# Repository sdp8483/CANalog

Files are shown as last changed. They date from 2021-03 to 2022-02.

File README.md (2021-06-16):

# CANalog

CAN to analog converter.

## TODO
### PCB
- [x] Add resistor to stm32 reset line so that stm32 programmer can reset uC when esp8266 is pulling pin high
- [x] Increase clearance between terminals and mounting holes by about 1mm
- [x] Increase spacing between aout terminal and CAN terminal, possibly center CAN terminal.
### WiFi Interface Firmware
- [ ] fix webpage layout for mobile devices
- [ ] aout control for analog calibration
- [ ] setup over the air update for esp8266 firmware
### CAN Interface Firmware
- [ ] LED persistance for CAN activity
- [ ] setup bootloader over spi for wifi update of firmware
- [ ] setup CAN filtering
- [ ] test std ID CAN messages
- [ ] test timing

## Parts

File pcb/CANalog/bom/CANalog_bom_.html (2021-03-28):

Source File | CANalog.sch
BoM Date | Sun 28 Mar 2021 03:16:26 PM EDT
Schematic Version
Schematic Date
PCB Variant | default
KiCad Version | Eeschema 5.1.9
Component Groups | 49
Component Count (per PCB) | 83
Fitted Components (per PCB) | 83
Number of PCBs | 1
Total Component Count (for 1 PCBs) | 83
 | Description | Part | References | Value | Footprint | Quantity Per PCB | Datasheet | Population
1 | Unpolarized capacitor | C | C9 | 33pF | C_0603_1608Metric | 1 | ~
2 | Unpolarized capacitor | C | C3 C5 C6 C8 C10 C11 | 100nF |  | 6 | ~
3 | Unpolarized capacitor | C | C4 C12 C16 C18 C19 | 0.1uF | C_0805_2012Metric | 5 | ~
4 | Unpolarized capacitor | C | C2 C13 C15 | 1uF |  | 3 | ~
5 | Unpolarized capacitor | C | C17 | 1uF | C_0805_2012Metric | 1 | ~
6 | Unpolarized capacitor | C | C1 | 4.7uF | C_0805_2012Metric | 1 | ~
7 | Unpolarized capacitor | C | C7 C14 | 10uF | C_0805_2012Metric | 2 | ~
8 | Diode | D | D9 | 1N4148 | D_DO-35_SOD27_P7.62mm_Horizontal | 1 | ~
9 | Zener diode | D_Zener | D1 | BZV55-C15 | Nexperia_BZV55_SOD80C | 1 | ~
10 | Diode | D | D5 | D |  | 1 | ~
11 | Light emitting diode | LED | D3 D6 D7 D8 | LED | LED_0603_1608Metric | 4 | ~
12 |  | PESD1CAN-UX | D10 | PESD1CAN-UX | SOT-323_SC-70 | 1
13 | Schottky diode | D_Schottky | D2 D4 | SS14F | SMAF | 2 | ~
14 | Ferrite bead, small symbol | Ferrite_Bead_Small | FB1 FB2 | FBS |  | 2 | ~
15 | Generic connector, single row, 01x03, script generated (kicad-library-utils/schlib/autogen/connector/) | Conn_01x03 | J8 | CAN |  | 1 | ~
16 | Generic connector, single row, 01x06, script generated (kicad-library-utils/schlib/autogen/connector/) | Conn_01x06 | J6 | ESP_PROG | PinHeader_1x06_P2.54mm_Vertical | 1 | ~
17 | Generic connector, single row, 01x04, script generated (kicad-library-utils/schlib/autogen/connector/) | Conn_01x04 | J4 J5 | I2C2 |  | 2 | ~ | DNP
18 | Generic connector, single row, 01x02, script generated (kicad-library-utils/schlib/autogen/connector/) | Conn_01x02 | J1 J7 | PWR | WJ127-5.0-2P | 2 | ~
19 | Generic connector, single row, 01x06, script generated (kicad-library-utils/schlib/autogen/connector/) | Conn_01x06 | J3 | SPI3 |  | 1 | ~ | DNP
20 | USB Micro Type B connector | USB_B_Micro | J2 | USB_B_Micro | USB_Micro-B_Amphenol_10103594-0001LF_Horizontal | 1 | ~
21 | Jumper, normally open, small symbol | Jumper_NO_Small | JP3 | BOOT0 | PinHeader_1x02_P2.54mm_Vertical | 1 | ~
22 | Jumper, normally closed, small symbol | Jumper_NC_Small | JP1 JP2 | NC |  | 2 | ~
23 | Inductor | L | L1 | 2.2uH | L_3.5mmx3.0mm_SMD | 1 | ~
24 | P-MOSFET transistor, gate/source/drain | Q_PMOS_GSD | Q1 Q3 | DMP3099L-7 | SOT-23 | 2 | ~
25 | NPN transistor, base/emitter/collector | Q_NPN_BEC | Q2 | MMBT2222A | SOT-23 | 1 | ~
26 | Resistor | R | R1 R2 | 0 | R_0805_2012Metric | 2 | ~
27 | Resistor | R | R26 | 120 | R_0805_2012Metric | 1 | ~
28 | Resistor | R | R8 R11 R22 R23 R24 | 1k | R_0805_2012Metric | 5 | ~
29 | Resistor | R | R7 | 1.5k | R_0805_2012Metric | 1 | ~
30 | Resistor | R | R3 R4 R12 R15 R16 R17 | 10k | R_0805_2012Metric | 6 | ~
31 | Resistor | R | R18 | 10k |  | 1 | ~
32 | Resistor | R | R20 | 12k | R_0805_2012Metric | 1 | ~
33 | Resistor | R | R5 R6 | 20k | R_0805_2012Metric | 2 | ~
34 | Resistor | R | R10 | 21k | R_0805_2012Metric | 1 | ~
35 | Resistor | R | R21 | 68k | R_0805_2012Metric | 1 | ~
36 | Resistor | R | R19 | 120k | R_0805_2012Metric | 1 | ~
37 | Resistor | R | R9 | 124k | R_0805_2012Metric | 1 | ~
38 | Resistor | R | R13 R14 | R |  | 2 | ~ | DNP
39 | Resistor | R | R25 | R | R_0805_2012Metric | 1 | ~
40 | Push button switch, generic, two pins | SW_Push | SW1 SW2 | SW_Push | SW_PUSH_6mm | 2 | ~
41 |  | 74AHC1G66 | U7 | 74AHC1G66 | SOT-353_SC-70-5 | 1
42 | DCD Step Down Converter | BL9342 | U1 | BL9342 | SOT-23-6 | 1 | https://datasheet.lcsc.com/szlcsc/1809050135_BL-Shanghai-Belling-BL9342_C93176.pdf
43 | ESP8266 ESP-12E module, 22 pins, 2mm, PCB antenna | ESP-12E | U5 | ESP-12E | ESP-12E_SMD | 1 | http://l0l.org.uk/2014/12/esp8266-modules-hardware-guide-gotta-catch-em-all/
44 | Low-Voltage Rail-to-Rail Output Operational Amplifiers, SOT-23-5/SC-70-5 | LMV321 | U2 | LMV321 |  | 1 | http://www.ti.com/lit/ds/symlink/lmv324.pdf
45 | 300mA Low-dropout Voltage Regulator, Vout 3.3V, Vin up to 5.5V, SOT-23 | MIC5504-3.3YM5 | U4 | MIC5504-3.3YM5 | SOT-23-5 | 1 | http://ww1.microchip.com/downloads/en/DeviceDoc/MIC550X.pdf
46 | 50μV V OS, 0.25μV/°C, 35μA CMOS OPERATIONAL AMPLIFIERS, Zerø-Drift Series, SOT | OPA330xxDBV | U6 | OPA330xxDBV | SOT-23-5 | 1 | http://www.ti.com/lit/ds/symlink/opa330.pdf
47 | CAN Bus Transceivers, 3.3V, 1Mbps, Low-Power capabilities, SOIC-8 | SN65HVD230 | U8 | SN65HVD230 | SOIC-8_3.9x4.9mm_P1.27mm | 1 | http://www.ti.com/lit/ds/symlink/sn65hvd230.pdf
48 | ARM Cortex-M4 MCU, 64KB flash, 16KB RAM, 72MHz, 2-3.6V, 37 GPIO, LQFP-48 | STM32F302C8Tx | U3 | STM32F302C8Tx | LQFP-48_7x7mm_P0.5mm | 1 | http://www.st.com/st-web-ui/static/active/en/resource/technical/document/datasheet/DM00093333.pdf
49 | Three pin ceramic resonator | Resonator | Y1 | 16MHz |  | 1 | ~ | DNP

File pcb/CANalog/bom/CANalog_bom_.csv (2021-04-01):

Component | Description | Part | References | Value | Footprint | Quantity Per PCB | Datasheet | MPN | Manufacture | SPN | Supplier | Supplier Link | Population
1 | Unpolarized capacitor | C | C9 | 33pF | C_0603_1608Metric | 1 | https://datasheet.lcsc.com/szlcsc/1912111437_Chinocera-HGC0603G0330J500NTHJ_C465159.pdf | HGC0603G0330J500NTHJ | Chinocera | C465159 | LCSC | https://lcsc.com/product-detail/Multilayer-Ceramic-Capacitors-MLCC-SMD-SMT_Chinocera-HGC0603G0330J500NTHJ_C465159.html
2 | Unpolarized capacitor | C | C3 C4 C5 C6 C8 C10 C11 C12 C16 C17 C19 | 100nF | C_0603_1608Metric | 11 | https://api.kemet.com/component-edge/download/datasheet/C0603C104Z3VACTU.pdf | C0603C104Z3VACTU | KEMET | 399-1100-1-ND | DigiKey | https://www.digikey.com/en/products/detail/kemet/C0603C104Z3VACTU/411099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
3 | Unpolarized capacitor | C | C2 C14 C15 C18 | 1uF | C_0603_1608Metric | 4 | https://www.samsungsem.com/resources/file/global/support/product_catalog/MLCC.pdf | CL10A105KQ8NNNC | Samsung Electro-Mechanics | 1276-1036-1-ND | DigiKey | https://www.digikey.com/en/products/detail/samsung-electro-mechanics/CL10A105KQ8NNNC/3886694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
4 | Unpolarized capacitor | C | C1 | 4.7uF | C_0805_2012Metric | 1 | https://datasheet.lcsc.com/szlcsc/1810191224_Samsung-Electro-Mechanics-CL21A475KBQNNNE_C98192.pdf | CL21A475KBQNNNE | Samsung Electro-Mechanics | C98192 | LCSC | https://lcsc.com/product-detail/Multilayer-Ceramic-Capacitors-MLCC-SMD-SMT_Samsung-Electro-Mechanics-CL21A475KBQNNNE_C98192.html
5 | Unpolarized capacitor | C | C7 C13 | 10uF | C_0805_2012Metric | 2 | https://datasheet.lcsc.com/szlcsc/1811011704_Samsung-Electro-Mechanics-CL21A106KPFNNNE_C17024.pdf | CL21A106KPFNNNE | Samsung Electro-Mechanics | C17024 | LCSC | https://lcsc.com/product-detail/Multilayer-Ceramic-Capacitors-MLCC-SMD-SMT_Samsung-Electro-Mechanics-CL21A106KPFNNNE_C17024.html
6 | Schottky diode | D_Schottky | D4 D6 | 1N4148W | D_SOD-123 | 2 | https://datasheet.lcsc.com/szlcsc/1809052017_MDD-Microdiode-Electronics-1N4148W_C84367.pdf | 1N4148W | Microdiode Electronics | C84367 | LCSC | https://lcsc.com/product-detail/Switching-Diode_MDD-Microdiode-Electronics-1N4148W_C84367.html
7 | Zener diode | D_Zener | D2 | 4.7V | D_SOD-123 | 1 | https://datasheet.lcsc.com/szlcsc/1811051603_MDD-Microdiode-Electronics-BZT52C4V7_C173408.pdf | BZT52C4V7 | MDD(Microdiode Electronics) | C173408 | LCSC | https://lcsc.com/product-detail/Zener-Diodes_MDD-Microdiode-Electronics-BZT52C4V7_C173408.html
8 | Light emitting diode | LED | D10 | BLU | LED_0603_1608Metric | 1 | https://datasheet.lcsc.com/szlcsc/1811100911_Orient-ORH-B36G_C193191.pdf | ORH-B36G | Orient | C193191 | LCSC | https://lcsc.com/product-detail/Light-Emitting-Diodes-LED_Orient-ORH-B36G_C193191.html
9 | Zener diode | D_Zener | D1 | BZV55-C15 | Nexperia_BZV55_SOD80C | 1 | https://rocelec.widen.net/view/pdf/mmjrjopmpw/PHGLS22257-1.pdf?t.download=true&u=5oefqw | BZV55-C15,115 | Nexperia USA Inc. | 1727-4962-1-ND | DigiKey | https://www.digikey.com/en/products/detail/nexperia-usa-inc/BZV55-C15-115/1155548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
10 | Light emitting diode | LED | D7 | GRN | LED_0603_1608Metric | 1 | https://datasheet.lcsc.com/szlcsc/1811092313_Orient-ORH-G36G_C205443.pdf | ORH-G36G | Orient | C205443 | LCSC | https://lcsc.com/product-detail/Light-Emitting-Diodes-LED_Orient-ORH-G36G_C205443.html
11 | Light emitting diode | LED | D8 | ORG | LED_0603_1608Metric | 1 | https://datasheet.lcsc.com/szlcsc/2008201033_Foshan-NationStar-Optoelectronics-NCD0603O1_C84269.pdf | NCD0603O1 | Foshan NationStar Optoelectronics | C84269 | LCSC | https://lcsc.com/product-detail/Light-Emitting-Diodes-LED_Foshan-NationStar-Optoelectronics-NCD0603O1_C84269.html
12 |  | PESD1CAN-UX | D11 | PESD1CAN | SOT-23 | 1 | https://datasheet.lcsc.com/szlcsc/2010221035_TECH-PUBLIC-PESD1CAN_C907838.pdf | PESD1CAN | TECH PUBLIC | C907838 | LCSC | https://lcsc.com/product-detail/Diodes-ESD_TECH-PUBLIC-PESD1CAN_C907838.html
13 | Light emitting diode | LED | D9 | RED | LED_0603_1608Metric | 1 | https://datasheet.lcsc.com/szlcsc/2008201032_Foshan-NationStar-Optoelectronics-NCD0603R1_C84263.pdf | NCD0603R1 | Foshan NationStar Optoelectronics | C84263 | LCSC | https://lcsc.com/product-detail/Light-Emitting-Diodes-LED_Foshan-NationStar-Optoelectronics-NCD0603R1_C84263.html
14 | Schottky diode | D_Schottky | D3 D5 | SS14F | SMAF | 2 | https://datasheet.lcsc.com/szlcsc/1811031612_Shandong-Jingdao-Microelectronics-SS14F_C108832.pdf | SS14F | Shandong Jingdao Microelectronics | C108832 | LCSC | https://lcsc.com/product-detail/Schottky-Barrier-Diodes-SBD_Shandong-Jingdao-Microelectronics-SS14F_C108832.html
15 | Resettable fuse, polymeric positive temperature coefficient | Polyfuse | F1 | 500mA | Fuse_0603_1608Metric_Castellated | 1 | https://datasheet.lcsc.com/szlcsc/2103231635_BHFUSE-BSMD0603-050-6V_C883095.pdf | BSMD0603-050-6V | BHFUSE | C883095 | LCSC | https://lcsc.com/product-detail/PTC-Resettable-Fuses_BHFUSE-BSMD0603-050-6V_C883095.html
16 | Ferrite bead, small symbol | Ferrite_Bead_Small | FB1 | FBS | L_0603_1608Metric | 1 | https://datasheet.lcsc.com/szlcsc/2009171304_TAI-TECH-FCM1608KF-600T07_C133931.pdf | FCM1608KF-600T07 | TAI-TECH | C133931 | LCSC | https://lcsc.com/product-detail/Ferrite-Beads_TAI-TECH-FCM1608KF-600T07_C133931.html
17 | Generic connector, single row, 01x03, script generated (kicad-library-utils/schlib/autogen/connector/) | Conn_01x03 | J8 | CAN | WJ127-5.0-3P | 1 | https://datasheet.lcsc.com/szlcsc/1912251633_Ningbo-Kangnex-Elec-WJ127-5-0-3P_C8393.pdf | WJ127-5.0-3P | Ningbo Kangnex Elec | C8393 | LCSC | https://lcsc.com/product-detail/Screw-terminal_Ningbo-Kangnex-Elec-WJ127-5-0-3P_C8393.html
18 | Generic connector, single row, 01x04, script generated (kicad-library-utils/schlib/autogen/connector/) | Conn_01x04 | J4 J5 | I2C2 | PinHeader_1x04_P2.54mm_Vertical | 2 | ~ |  |  |  |  |  | DNP
19 | Generic connector, single row, 01x02, script generated (kicad-library-utils/schlib/autogen/connector/) | Conn_01x02 | J1 J7 | PWR | WJ127-5.0-2P | 2 | https://datasheet.lcsc.com/szlcsc/1912251631_Ningbo-Kangnex-Elec-WJ127-5-0-2P_C3703.pdf | WJ127-5.0-2P | Ningbo Kangnex Elec | C3703 | LCSC | https://lcsc.com/product-detail/Screw-terminal_Ningbo-Kangnex-Elec-WJ127-5-0-2P_C3703.html
20 | Generic connector, single row, 01x06, script generated (kicad-library-utils/schlib/autogen/connector/) | Conn_01x06 | J3 J6 | SPI3 | PinHeader_1x06_P2.54mm_Vertical | 2 | ~ |  |  |  |  |  | DNP
21 | USB Micro Type B connector | USB_B_Micro | J2 | USB_B_Micro | USB_Micro-B_Molex-105017-0001 | 1 | https://datasheet.lcsc.com/szlcsc/2002271812_XKB-Connectivity-U254-051T-4BHJ25-S2S_C319163.pdf | U254-051T-4BHJ25-S2S | XKB Connectivity | C319163 | LCSC | https://lcsc.com/product-detail/USB-Connectors_XKB-Connectivity-U254-051T-4BHJ25-S2S_C319163.html
22 | Jumper, normally open, small symbol | Jumper_NO_Small | JP3 | BOOT0 | PinHeader_1x02_P2.54mm_Vertical | 1 | ~ |  |  |  |  |  | DNP
23 | Jumper, normally closed, small symbol | Jumper_NC_Small | JP1 | NC | SolderJumper-2_P1.3mm_Bridged_RoundedPad1.0x1.5mm | 1 | ~ |  |  |  |  |  | DNP
24 | Jumper, 3-pole, pins 1+2 closed/bridged | Jumper_3_Bridged12 | JP4 | PSELECT | SolderJumper-3_P1.3mm_Bridged2Bar12_Pad1.0x1.5mm | 1 | ~
25 | Inductor | L | L1 | 2.2uH | L_3.5mmx3.0mm_SMD | 1 | https://datasheet.lcsc.com/szlcsc/2011091134_PROD-Tech-PSPCAQ32-2R2M_C436276.pdf | PSPCAQ32-2R2M | PROD Tech | C436276 | LCSC | https://lcsc.com/product-detail/Power-Inductors_PROD-Tech-PSPCAQ32-2R2M_C436276.html
26 | Net tie, 2 pins | Net-Tie_2 | NT1 | Net-Tie_2 | NetTie-2_SMD_Pad0.5mm | 1 | ~
27 | P-MOSFET transistor, gate/source/drain | Q_PMOS_GSD | Q1 Q3 | DMP3099L-7 | SOT-23 | 2 | https://www.diodes.com/assets/Datasheets/DMP3099L.pdf | DMP3099L-7 | Diodes Incorporated | DMP3099L-7DICT-ND | DigiKey | https://www.digikey.com/en/products/detail/diodes-incorporated/DMP3099L-7/4471075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
28 | NPN transistor, base/emitter/collector | Q_NPN_BEC | Q2 | MMBT2222A | SOT-23 | 1 | https://datasheet.lcsc.com/szlcsc/2012041134_JSMSEMI-MMBT2222A_C916372.pdf | MMBT2222A | JSMSEMI | C916372 | LCSC | https://lcsc.com/product-detail/Transistors-NPN-PNP_JSMSEMI-MMBT2222A_C916372.html
29 | Resistor | R | R1 R2 | 0 | R_0603_1608Metric | 2 | https://datasheet.lcsc.com/szlcsc/1809281528_YAGEO-RC0603JR-070RL_C95177.pdf | RC0603JR-070RL | YAGEO | C95177 | LCSC | https://lcsc.com/product-detail/Chip-Resistor-Surface-Mount_0R-0R-5_C95177.html
30 | Resistor | R | R32 | 120 | R_0603_1608Metric | 1 | https://datasheet.lcsc.com/szlcsc/1811061723_FH-Guangdong-Fenghua-Advanced-Tech-RS-03K1200FT_C310266.pdf | RS-03K1200FT | FH(Guangdong Fenghua Advanced Tech) | C310266 | LCSC | https://lcsc.com/product-detail/Chip-Resistor-Surface-Mount_FH-Guangdong-Fenghua-Advanced-Tech-RS-03K1200FT_C310266.html
31 | Resistor | R | R14 R16 R17 R18 R28 R29 R30 R31 | 1k | R_0603_1608Metric | 8 | https://www.yageo.com/upload/media/product/productsearch/datasheet/rchip/PYu-RC_Group_51_RoHS_L_11.pdf | RC0603JR-071KL | YAGEO | 311-1.0KGRCT-ND | DigiKey | https://www.digikey.com/en/products/detail/yageo/RC0603JR-071KL/726677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 | DNP
32 | Resistor | R | R10 | 1.5k | R_0603_1608Metric | 1 | https://datasheet.lcsc.com/szlcsc/1811061750_FH-Guangdong-Fenghua-Advanced-Tech-RS-03K152JT_C118361.pdf | RS-03K152JT | FH(Guangdong Fenghua Advanced Tech) | C118361 | LCSC | https://lcsc.com/product-detail/Chip-Resistor-Surface-Mount_FH-Guangdong-Fenghua-Advanced-Tech-RS-03K152JT_C118361.html
33 | Resistor | R | R3 R4 R11 R15 R21 R22 R23 | 10k | R_0603_1608Metric | 7 | https://datasheet.lcsc.com/szlcsc/1811081617_YAGEO-RC0603JR-0710KL_C99198.pdf | RC0603JR-0710KL | YAGEO | C99198 | LCSC | https://lcsc.com/product-detail/Chip-Resistor-Surface-Mount_YAGEO-RC0603JR-0710KL_C99198.html
34 | Resistor | R | R9 R25 | 12k | R_0603_1608Metric | 2 | https://datasheet.lcsc.com/szlcsc/1811141450_YAGEO-RT0603BRD0712KL_C326735.pdf | RT0603BRD0712KL | YAGEO | C326735 | LCSC | https://lcsc.com/product-detail/Chip-Resistor-Surface-Mount_YAGEO-RT0603BRD0712KL_C326735.html
35 | Resistor | R | R5 R6 R8 | 20k | R_0603_1608Metric | 3 | https://datasheet.lcsc.com/szlcsc/1811081710_UNI-ROYAL-Uniroyal-Elec-0603WAJ0203T5E_C25586.pdf | 0603WAJ0203T5E | UNI-ROYAL(Uniroyal Elec) | C25586 | LCSC | https://lcsc.com/product-detail/Chip-Resistor-Surface-Mount_UNI-ROYAL-Uniroyal-Elec-0603WAJ0203T5E_C25586.html
36 | Resistor | R | R13 | 20.5k | R_0603_1608Metric | 1 | https://datasheet.lcsc.com/szlcsc/1912111437_UNI-ROYAL-Uniroyal-Elec-0603WAD2052T5E_C423063.pdf | 0603WAD2052T5E | UNI-ROYAL(Uniroyal Elec) | C423063 | LCSC | https://lcsc.com/product-detail/Chip-Resistor-Surface-Mount_UNI-ROYAL-Uniroyal-Elec-0603WAD2052T5E_C423063.html
37 | Resistor | R | R26 | 68k | R_0603_1608Metric | 1 | https://datasheet.lcsc.com/szlcsc/2010201905_YAGEO-RT0603BRD0768KL_C705793.pdf | RT0603BRD0768KL | YAGEO | C705793 | LCSC | https://lcsc.com/product-detail/Chip-Resistor-Surface-Mount_YAGEO-RT0603BRD0768KL_C705793.html
38 | Resistor | R | R7 R24 | 120k | R_0603_1608Metric | 2 | https://datasheet.lcsc.com/szlcsc/2008171235_YAGEO-RT0603BRD07120KL_C705720.pdf | RT0603BRD07120KL | YAGEO | C705720 | LCSC | https://lcsc.com/product-detail/Chip-Resistor-Surface-Mount_YAGEO-RT0603BRD07120KL_C705720.html
39 | Resistor | R | R12 | 124k | R_0603_1608Metric | 1 | https://datasheet.lcsc.com/szlcsc/1810170511_UNI-ROYAL-Uniroyal-Elec-0603WAF1243T5E_C22788.pdf | 0603WAF1243T5E | UNI-ROYAL(Uniroyal Elec) | C22788 | LCSC | https://lcsc.com/product-detail/Chip-Resistor-Surface-Mount_UNI-ROYAL-Uniroyal-Elec-0603WAF1243T5E_C22788.html
40 | Resistor | R | R19 R20 R27 | R | R_0603_1608Metric | 3 | ~ |  |  |  |  |  | DNP
41 | Push button switch, generic, two pins | SW_Push | SW2 | ESP_PROG | SW_SPST_CK_RS282G05A3 | 1 | https://datasheet.lcsc.com/szlcsc/1912111437_SHOU-HAN-TS3625A_C398053.pdf | TS3625A | SHOU HAN | C398053 | LCSC | https://lcsc.com/product-detail/Tactile-Switches_SHOU-HAN-TS3625A_C398053.html
42 | Push button switch, generic, two pins | SW_Push | SW1 | RESET | SW_SPST_CK_RS282G05A3 | 1 | https://datasheet.lcsc.com/szlcsc/1912111437_SHOU-HAN-TS3625A_C398053.pdf | TS3625A | SHOU HAN | C398053 | LCSC | https://lcsc.com/product-detail/Tactile-Switches_SHOU-HAN-TS3625A_C398053.html
43 |  | 74AHC1G66 | U8 | 74AHC1G66 | SOT-353_SC-70-5 | 1 | https://datasheet.lcsc.com/szlcsc/1809191939_Nexperia-74AHC1G66GW-125_C96224.pdf | 74AHC1G66GW,125 | Nexperia | C96224 | LCSC | https://lcsc.com/product-detail/Analog-Switches_Nexperia-74AHC1G66GW-125_C96224.html
44 | DCD Step Down Converter | BL9342 | U1 | BL9342 | SOT-23-6 | 1 | https://datasheet.lcsc.com/szlcsc/1809050135_BL-Shanghai-Belling-BL9342_C93176.pdf | BL9342 | BL(Shanghai Belling) | C93176 | LCSC | https://lcsc.com/product-detail/DC-DC-Converters_BL-Shanghai-Belling-BL9342_C93176.html
45 | ESP8266 ESP-12E module, 22 pins, 2mm, PCB antenna | ESP-12E | U4 | ESP-12F | ESP-12E_SMD | 1 | https://datasheet.lcsc.com/szlcsc/2102191804_Ai-Thinker-ESP-12F-ESP8266MOD_C82891.pdf | ESP-12F(ESP8266MOD) | Ai-Thinker | C82891 | LCSC | https://lcsc.com/product-detail/WIFI-Modules_Ai-Thinker-ESP-12F-ESP8266MOD_C82891.html
46 | 300mA Low-dropout Voltage Regulator, Vout 3.3V, Vin up to 5.5V, SOT-23 | MIC5504-3.3YM5 | U5 | MIC5504-3.3YM5 | SOT-23-5 | 1 | http://ww1.microchip.com/downloads/en/DeviceDoc/MIC550X.pdf | MIC5504-3.3YM5-TR | Microchip Technology | 576-4764-1-ND | DigiKey | https://www.digikey.com/en/products/detail/MIC5504-3.3YM5-TR/576-4764-1-ND/4864028?itemSeq=359217799
47 | 50μV V OS, 0.25μV/°C, 35μA CMOS OPERATIONAL AMPLIFIERS, Zerø-Drift Series, SOT | OPA330xxDBV | U6 | OPA330xxDBV | SOT-23-5 | 1 | http://www.ti.com/lit/ds/symlink/opa330.pdf | OPA330AIDBVR | Texas Instruments | C38649 | LCSC | https://lcsc.com/product-detail/Precision-OpAmps_Texas-Instruments-OPA330AIDBVR_C38649.html
48 | Low-Voltage Rail-to-Rail Output Operational Amplifiers, SOT-23-5/SC-70-5 | LMV321 | U2 | RS321BXF | SOT-23-5 | 1 | https://datasheet.lcsc.com/szlcsc/2010160334_Jiangsu-RUNIC-Tech-RS321BXF_C237022.pdf | RS321BXF | Jiangsu RUNIC Tech | C237022 | LCSC | https://lcsc.com/product-detail/General-Purpose-Amplifiers_Jiangsu-RUNIC-Tech-RS321BXF_C237022.html
49 | CAN Bus Transceivers, 3.3V, 1Mbps, Low-Power capabilities, SOIC-8 | SN65HVD230 | U7 | SN65HVD230 | SOIC-8_3.9x4.9mm_P1.27mm | 1 | http://www.ti.com/lit/ds/symlink/sn65hvd230.pdf | SN65HVD230DR | Texas Instruments | C12084 | LCSC | https://lcsc.com/product-detail/CAN-ICs_Texas-Instruments-SN65HVD230DR_C12084.html
50 | ARM Cortex-M4 MCU, 64KB flash, 16KB RAM, 72MHz, 2-3.6V, 37 GPIO, LQFP-48 | STM32F302C8Tx | U3 | STM32F302C8T6 | LQFP-48_7x7mm_P0.5mm | 1 | http://www.st.com/st-web-ui/static/active/en/resource/technical/document/datasheet/DM00093333.pdf | STM32F302C8T6 | STMicroelectronics | 511-STM32F302C8T6 | Mouser | https://www.mouser.com/ProductDetail/511-STM32F302C8T6
51 | Three pin ceramic resonator | Resonator | Y1 | 16MHz | Resonator_SMD_muRata_CSTxExxV-3Pin_3.0x1.1mm | 1 | https://www.mouser.com/datasheet/2/281/murata_04192018_CSTN_CeramResonCERAL-1323383.pdf | CSTNE16M0VH3C000R0 | Murata Electronics | 81-CSTNE16M0VH3C000R | Mouser | https://www.mouser.com/ProductDetail/81-CSTNE16M0VH3C000R | DNP
Component Groups: | 51
Component Count: | 91
Fitted Components: | 91
Number of PCBs: | 1
Total components: | 91
Schematic Version:
Schematic Date:
PCB Variant: | default
BoM Date: | Wed 31 Mar 2021 07:13:59 PM EDT
Schematic Source: | CANalog.sch
KiCad Version: | Eeschema 5.1.9

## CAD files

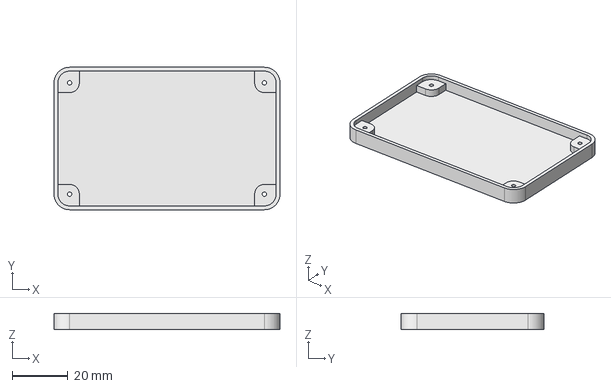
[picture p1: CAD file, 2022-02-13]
enclosure/tag-connect_base.FCStd
81.2 x 51.2 x 5.80 mm

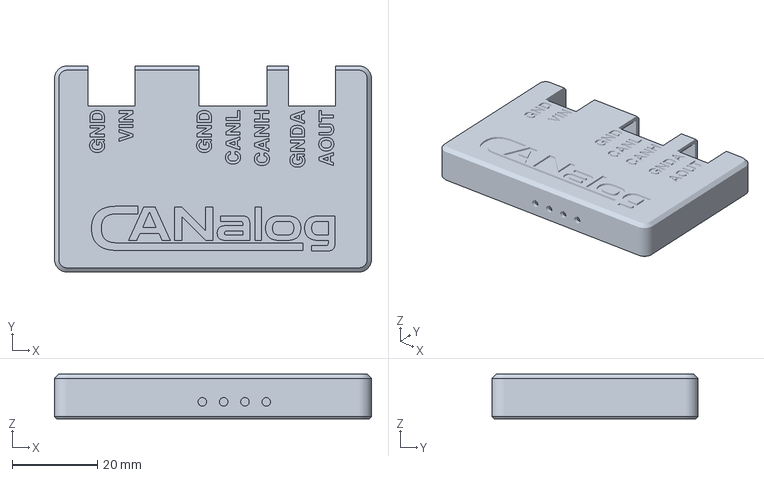
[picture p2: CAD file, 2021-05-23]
enclosure/CANalog_V1-Enclosuretop.amf
74.4 x 48.4 x 10.5 mm

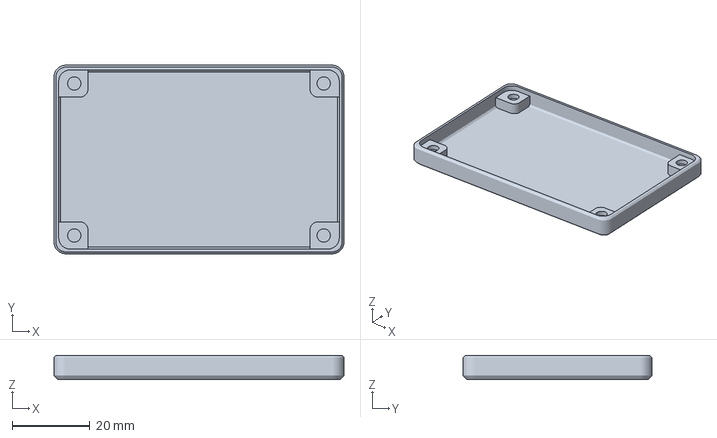
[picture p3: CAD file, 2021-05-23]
enclosure/CANalog_V1-Enclosurebottom.amf
74.4 x 48.4 x 6.20 mm

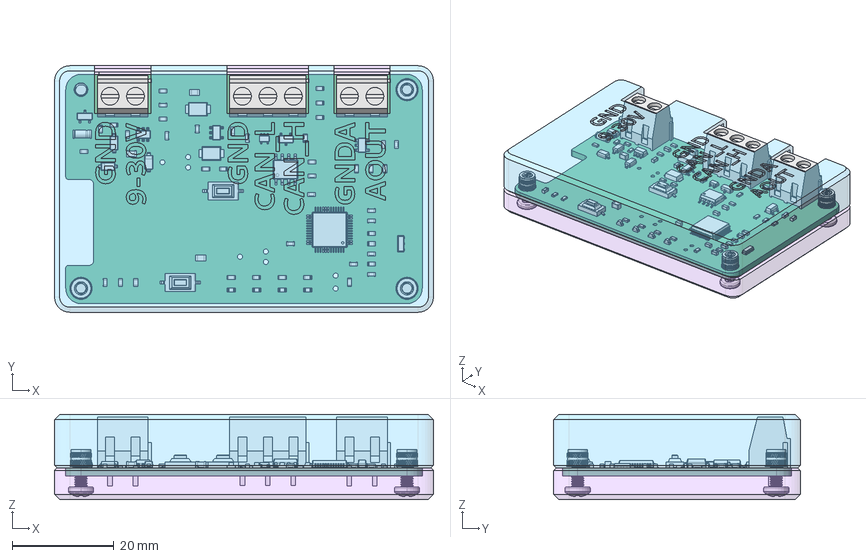
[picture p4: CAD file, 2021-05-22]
enclosure/CANalog_V1.FCStd
74.4 x 48.4 x 16.7 mm
Pcb_3227
R14_R_0603_1608Metric_6084B21E x 26
U3_LQFP_48_7x7mm_P05mm_6084B15A
FB1_L_0603_1608Metric_6084B0A4
Y1_muRata_CSTxExxV_608B31B9
U7_SOT_353_SC_70_5_607C6EF3
U6_SOIC_8_39x49mm_P127mm_607C6EDE
U5_SOT_23_5_608C0353 x 2
U1_SOT_23_6_607C6E11
SW2_SW_SPST_CK_RS282G05A3_607C6DF3 x 2
Q1_SOT_23_607CB52A x 2
J7_C-282836-3_608BF21D
J6_C-282836-2_607C6B76 x 2
D10_LED_0603_1608Metric_608BB388 x 4
D6_D_SOD_123_607CB6C2 x 3
D5_SMAF_607D967D x 2
D1_D_SOD-80C_60845F9F
C18_C_0603_1608Metric_607C69A6 x 15
C13_C_0805_2012Metric_60845A74 x 3
bottom
top
M2.5_insert_mcmaster
M2.5_insert_mcmaster001
M2.5_insert_mcmaster002
M2.5_insert_mcmaster003
2.5mm_bolt_mcmaster
2.5mm_bolt_mcmaster001
2.5mm_bolt_mcmaster002
2.5mm_bolt_mcmaster003

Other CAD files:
enclosure/tag-connect_base-base.amf

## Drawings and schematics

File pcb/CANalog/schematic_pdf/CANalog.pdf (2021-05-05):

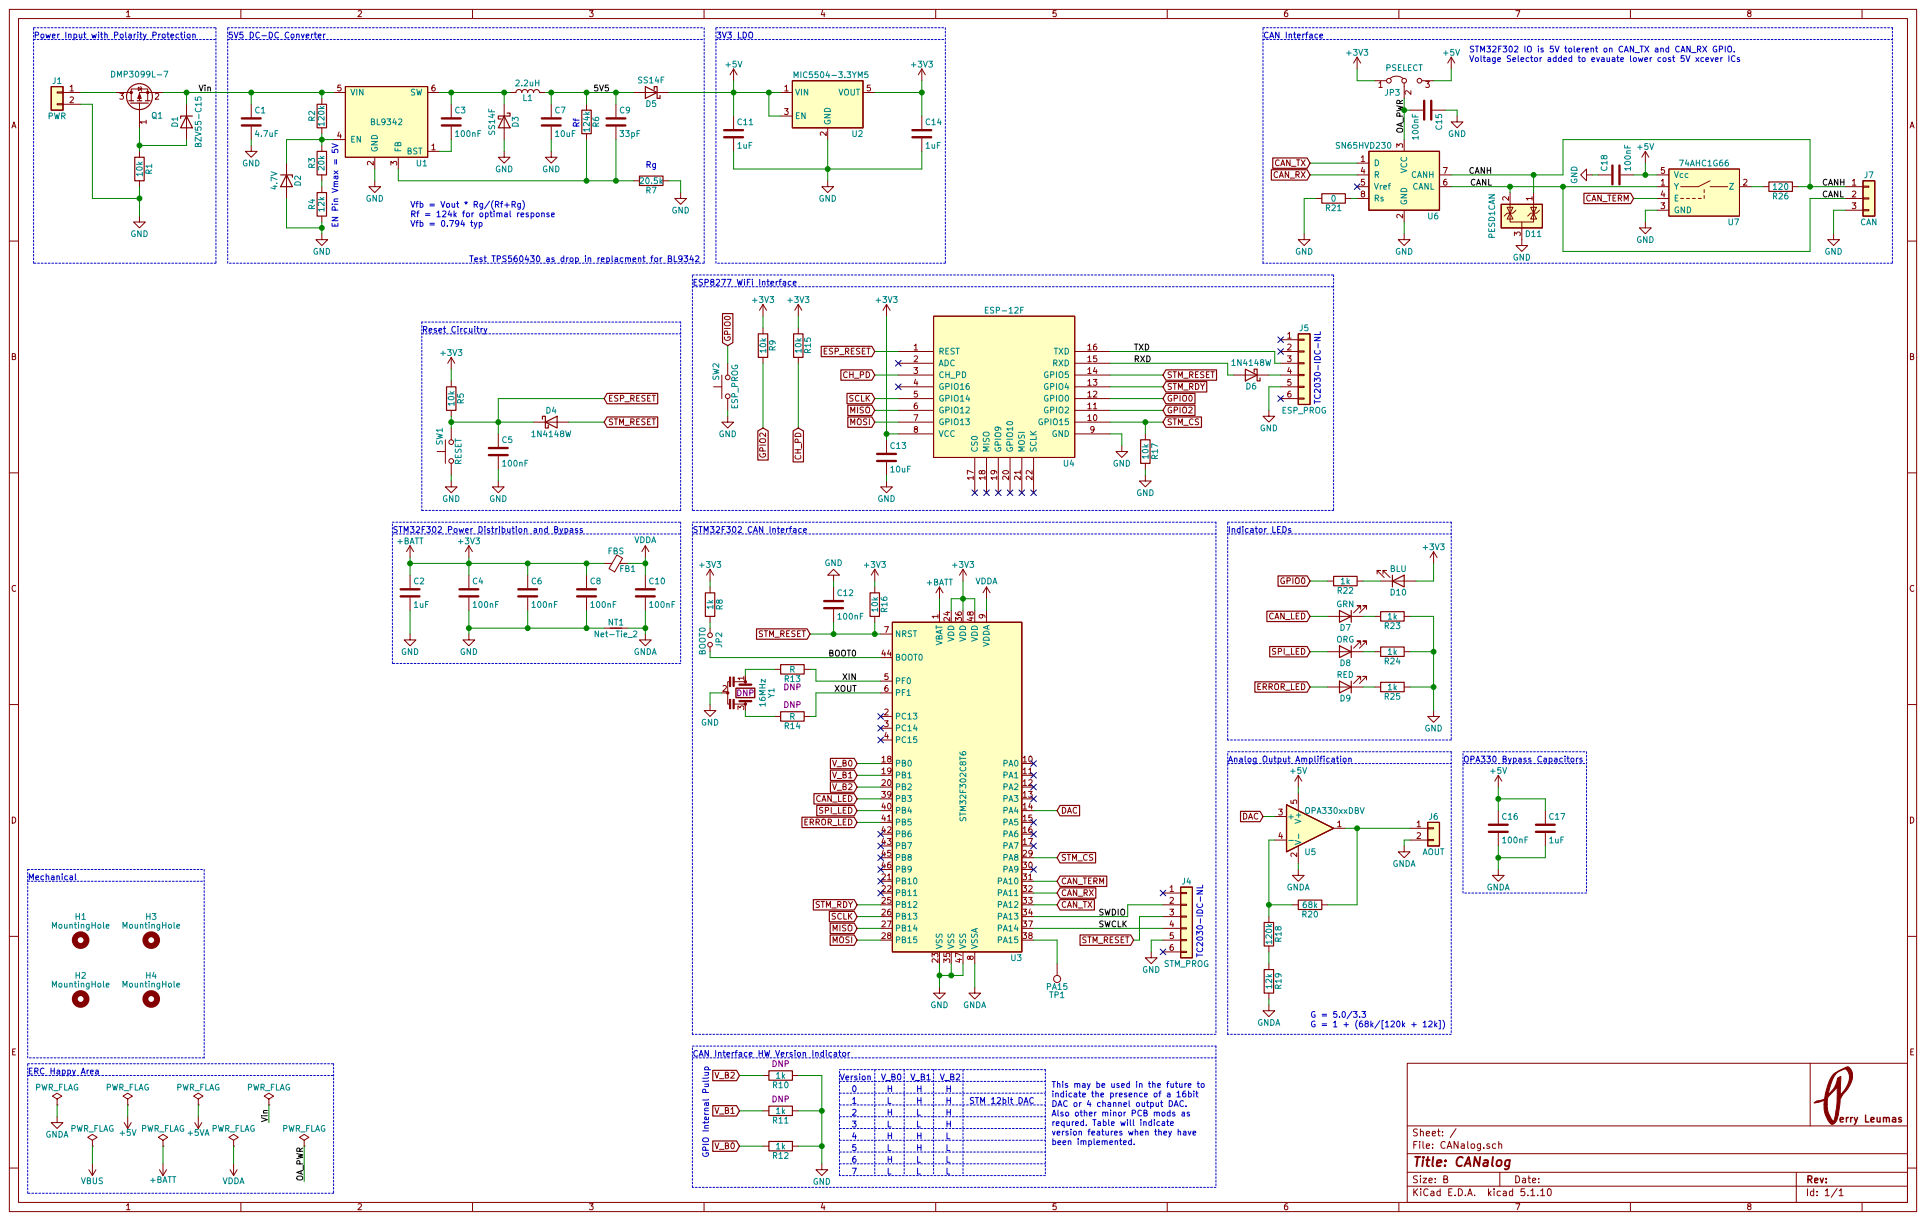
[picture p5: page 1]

Power Input with Polarity Protection

3V3 LDO EN Pin Vmax = 5V

CAN Interface Reset Circuitry
+3V3 +3V310k R5 GND

STM32F302 IO is 5V tolerent on CAN_TX and CAN_RX GPIO. Voltage Selector added to evauate lower cost 5V xcever ICs

2 EN 3 VOUT 5 U2 MIC5504-3.3YM5 GND GND

Vfb = Vout * Rg/(Rf+Rg)
Rf = 124k for optimal response

Test TPS560430 as drop in replacment for BL9342

1 VDD 24 VDD 36 VDD 48 VDDA

9 VSS 23 VSS 35 VSS 47 VSSA

SWCLK | 4

This may be used in the future to
indicate the presence of a 16bit
DAC or 4 channel output DAC. Also other minor PCB mods as requred. Table will indicate

2 | LH H | L | H

version features when they have
been implemented.

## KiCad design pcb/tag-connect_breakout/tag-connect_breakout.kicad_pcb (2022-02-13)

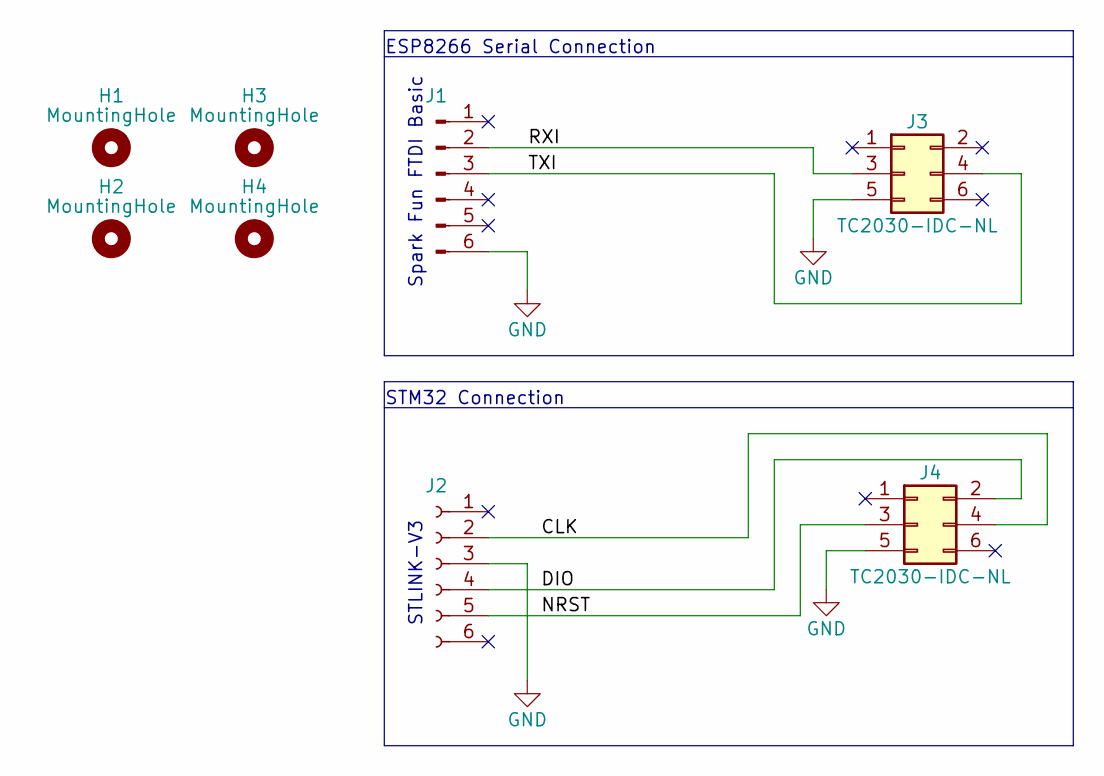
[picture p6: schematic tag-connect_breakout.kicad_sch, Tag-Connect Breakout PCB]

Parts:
H1, H2, H3, H4: MountingHole; MountingHole_3.2mm_M3
J1: Conn_01x06_Male; PinHeader_1x06_P2.54mm_Vertical
J2: Conn_01x06_Female; PinSocket_1x06_P2.54mm_Vertical
J3, J4: TC2030-IDC-NL; PinHeader_2x03_P2.54mm_Vertical

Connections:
/CLK: J2.2, J4.4
/DIO: J2.4, J4.2
/NRST: J2.5, J4.3
/RXI: J1.2, J3.3
/TXI: J1.3, J3.4
GND: J1.6, J2.3, J3.5, J4.5

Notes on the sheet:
Spark Fun FTDI Basic
STM32 Connection
ESP8266 Serial Connection
STLINK-V3

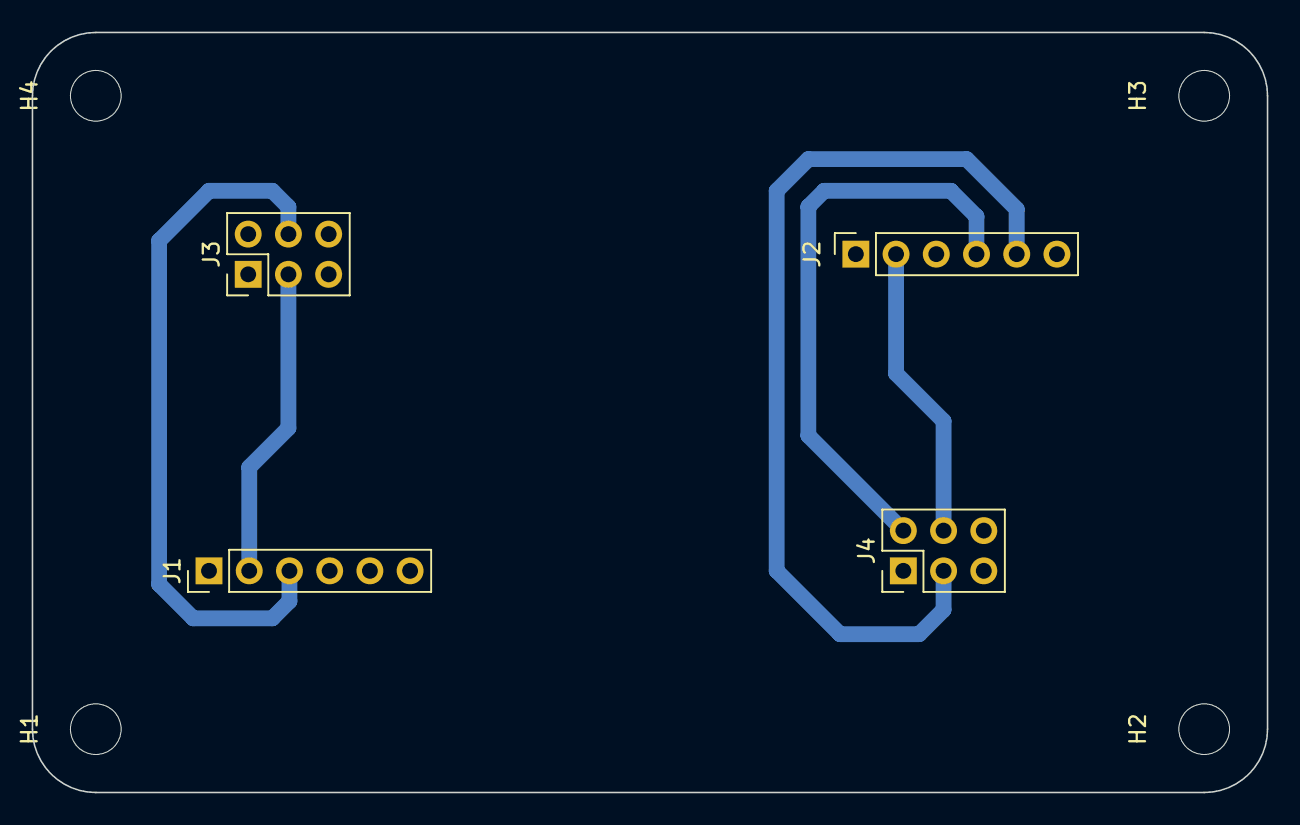
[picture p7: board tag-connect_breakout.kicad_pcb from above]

Board: 2 copper layers, 78.0 x 48.0 mm, 8 parts (0 on the bottom side), 6 nets.

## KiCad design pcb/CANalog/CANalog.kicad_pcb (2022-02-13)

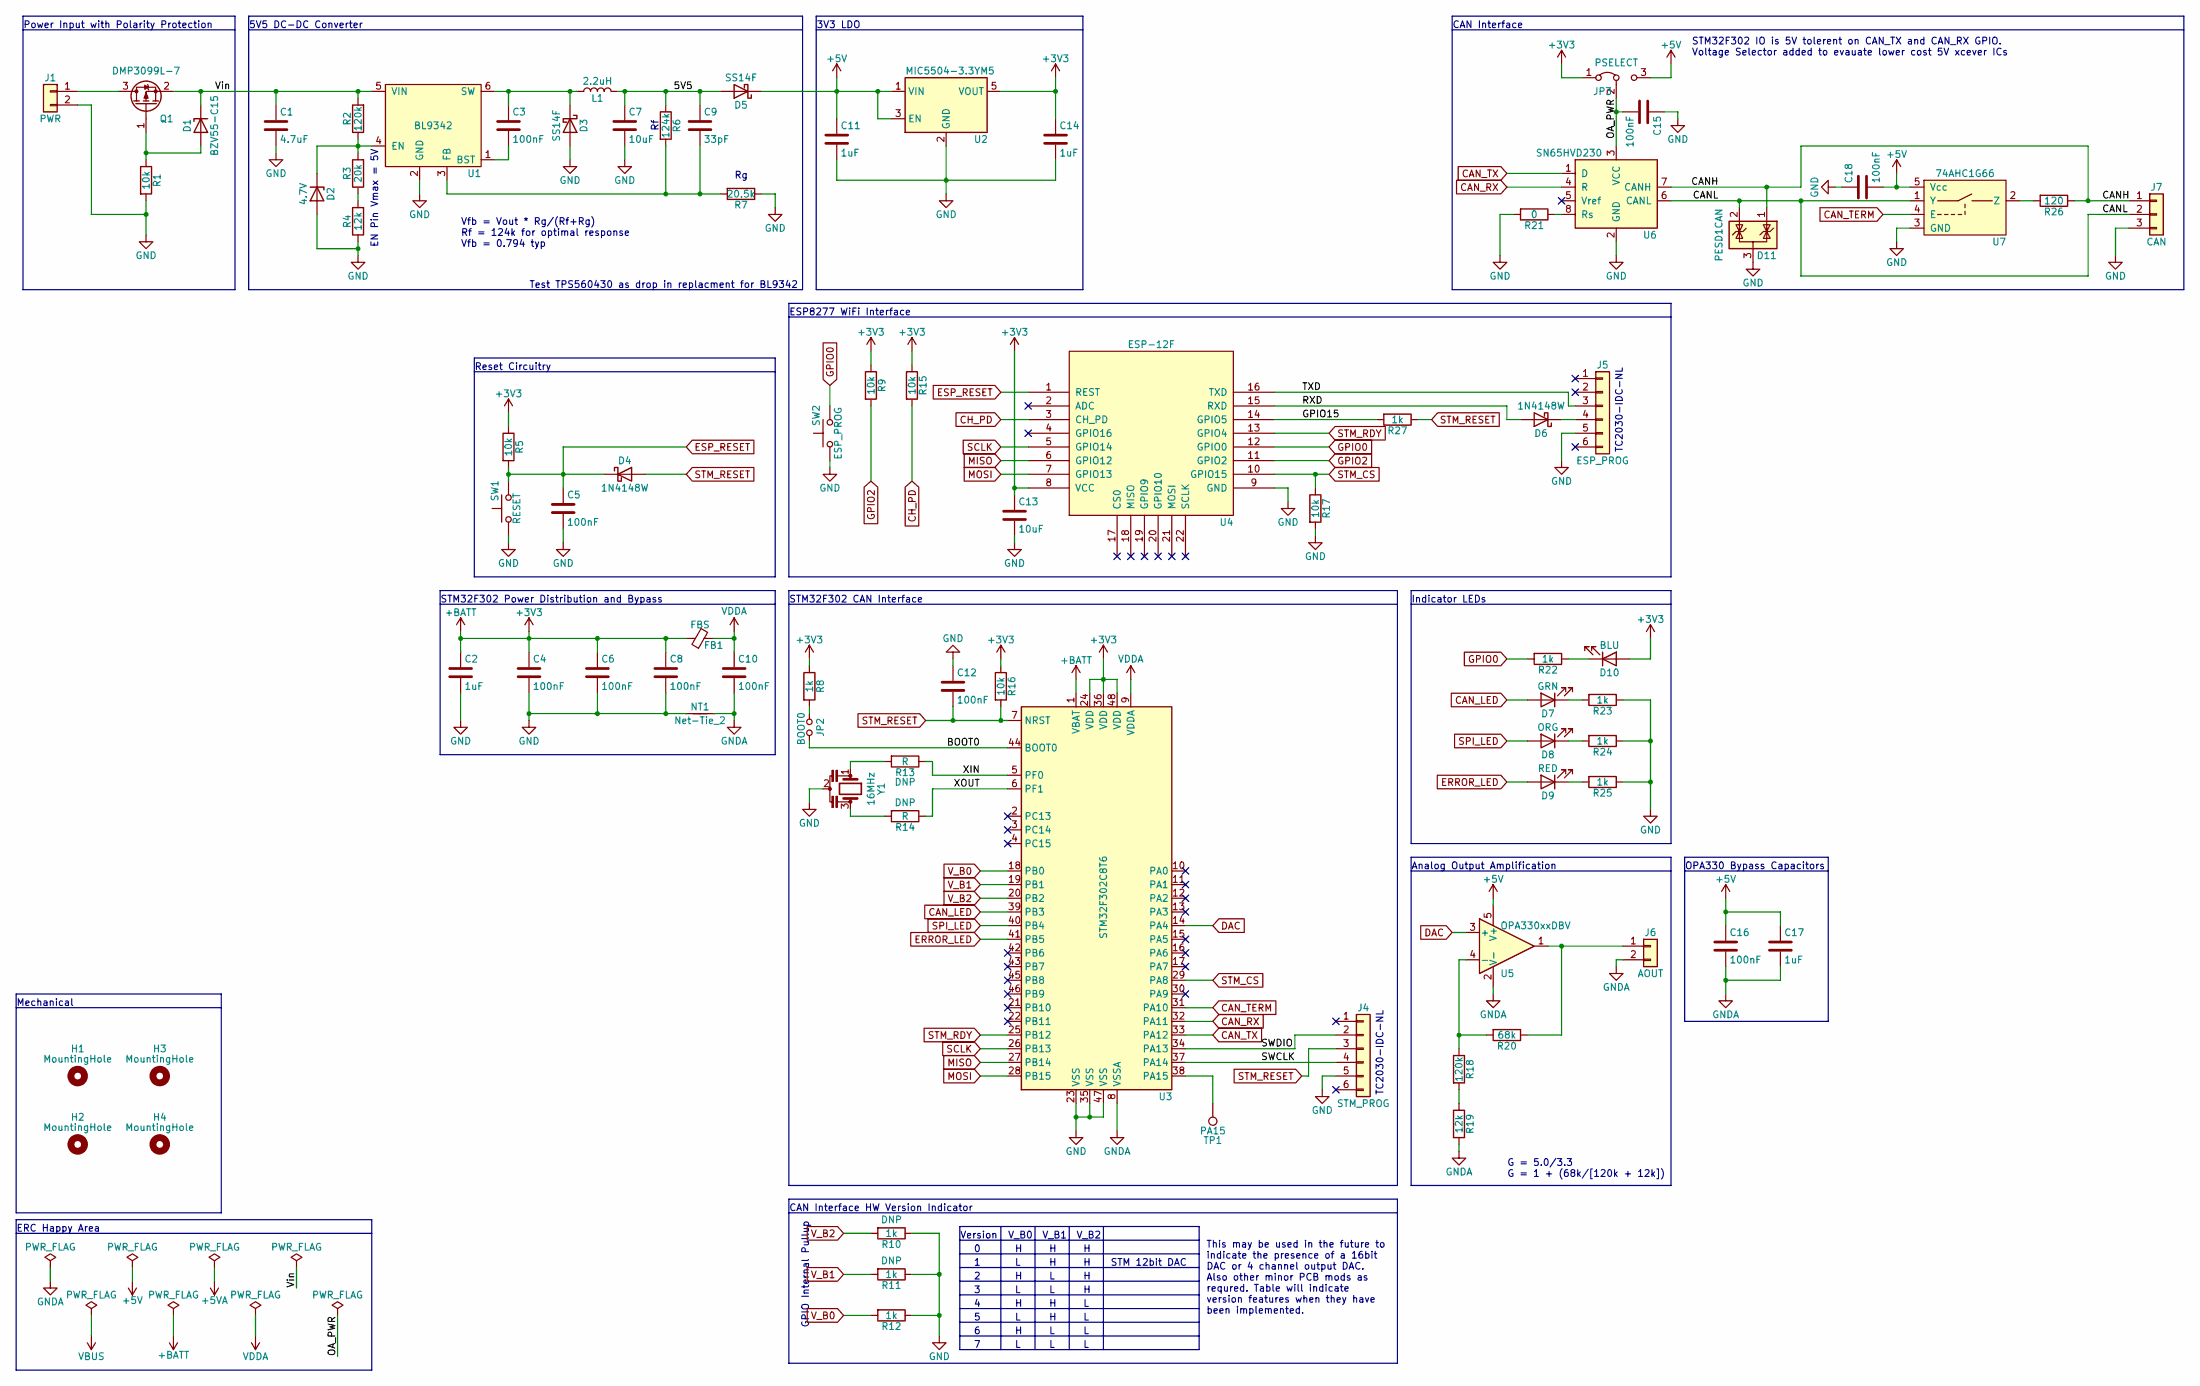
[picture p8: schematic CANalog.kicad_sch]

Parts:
C1: 4.7uF; C_0805_2012Metric; MPN CL21A475KBQNNNE
C2, C11, C14, C17: 1uF; C_0603_1608Metric; MPN CL10A105KQ8NNNC
C3, C4, C5, C6, C8, C10, C12, C15, C16, C18: 100nF; C_0603_1608Metric; MPN C0603C104Z3VACTU
C7, C13: 10uF; C_0805_2012Metric; MPN CL21A106KPFNNNE
C9: 33pF; C_0603_1608Metric; MPN HGC0603G0330J500NTHJ
D1: BZV55-C15; Nexperia_BZV55_SOD80C; MPN BZV55-C15,115
D2: 4.7V; D_SOD-123; MPN BZT52C4V7
D3, D5: SS14F; SMAF; MPN SS14F
D4, D6: 1N4148W; D_SOD-123; MPN 1N4148W
D7: GRN; LED_0603_1608Metric; MPN ORH-G36G
D8: ORG; LED_0603_1608Metric; MPN NCD0603O1
D9: RED; LED_0603_1608Metric; MPN NCD0603R1
D10: BLU; LED_0603_1608Metric; MPN ORH-B36G
D11: PESD1CAN; SOT-23; MPN PESD1CAN
FB1: FBS; L_0603_1608Metric; MPN FCM1608KF-600T07
H1, H2, H3, H4: MountingHole; MountingHole_2.7mm_M2.5
J1: PWR; WJ127-5.0-2P; MPN WJ127-5.0-2P
J4: STM_PROG; Tag-Connect_TC2030-IDC-NL_2x03_P1.27mm_Vertical
J5: ESP_PROG; Tag-Connect_TC2030-IDC-NL_2x03_P1.27mm_Vertical
J6: AOUT; WJ127-5.0-2P; MPN WJ127-5.0-2P
J7: CAN; WJ127-5.0-3P; MPN WJ127-5.0-3P
JP2: BOOT0; PinHeader_1x02_P2.54mm_Vertical
JP3: PSELECT; SolderJumper-3_P1.3mm_Bridged2Bar12_Pad1.0x1.5mm
L1: 2.2uH; L_3.5mmx3.0mm_SMD; MPN PSPCAQ32-2R2M
NT1: Net-Tie_2; NetTie-2_SMD_Pad0.5mm
Q1: DMP3099L-7; SOT-23; MPN DMP3099L-7
R1, R5, R9, R15, R16, R17: 10k; R_0603_1608Metric; MPN RC0603JR-0710KL
R2, R18: 120k; R_0603_1608Metric; MPN RT0603BRD07120KL
R3: 20k; R_0603_1608Metric; MPN 0603WAJ0203T5E
R4, R19: 12k; R_0603_1608Metric; MPN RT0603BRD0712KL
R6: 124k; R_0603_1608Metric; MPN 0603WAF1243T5E
R7: 20.5k; R_0603_1608Metric; MPN 0603WAD2052T5E
R8, R10, R11, R12, R22, R23, R24, R25, R27: 1k; R_0603_1608Metric; MPN RC0603JR-071KL
R13, R14: R; R_0603_1608Metric
R20: 68k; R_0603_1608Metric; MPN RT0603BRD0768KL
R21: 0; R_0603_1608Metric
R26: 120; R_0603_1608Metric; MPN RS-03K1200FT
SW1: RESET; SW_SPST_CK_RS282G05A3; MPN TS3625A
SW2: ESP_PROG; SW_SPST_CK_RS282G05A3; MPN TS3625A
TP1: PA15; TestPoint_Pad_D1.0mm
U1: BL9342; SOT-23-6; MPN BL9342
U2: MIC5504-3.3YM5; SOT-23-5; MPN MIC5504-3.3YM5-TR
U3: STM32F302C8T6; LQFP-48_7x7mm_P0.5mm; MPN STM32F302C8T6
U4: ESP-12F; ESP-12E_SMD; MPN ESP-12F(ESP8266MOD)
U5: OPA330xxDBV; SOT-23-5; MPN OPA330AIDBVR
U6: SN65HVD230; SOIC-8_3.9x4.9mm_P1.27mm; MPN SN65HVD230DR
U7: 74AHC1G66; SOT-353_SC-70-5; MPN 74AHC1G66GW,125
Y1: 16MHz; Resonator_SMD_muRata_CSTxExxV-3Pin_3.0x1.1mm; MPN CSTNE16M0VH3C000R0

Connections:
+3V3: C2.1, C4.1, C6.1, C8.1, C13.1, C14.1, D10.2 (A), FB1.1, JP3.1 (A), R5.1, R8.1, R9.1, R15.1, R16.1, U2.5 (VOUT), U3.1 (VBAT), U3.24 (VDD), U3.36 (VDD), U3.48 (VDD), U4.8 (VCC)
+5V: C11.1, C16.1, C17.1, C18.2, D5.1 (K), JP3.3 (B), U2.1 (VIN), U2.3 (EN), U5.5 (V+), U7.5 (Vcc)
/5V5: C7.1, C9.1, D5.2 (A), L1.2, R6.1
/BOOT0: JP2.2, U3.44 (BOOT0)
/CANH: D11.1 (K), J7.1, R26.1, U6.7 (CANH)
/CANL: D11.2 (K), J7.2, U6.6 (CANL), U7.1 (Y)
/GPIO15: R27.2, U4.14 (GPIO5)
/OA_PWR: C15.2, JP3.2 (C), U6.3 (VCC)
/RXD: D6.2 (A), U4.15 (RXD)
/SWCLK: J4.4, U3.37 (PA14)
/SWDIO: J4.2, U3.34 (PA13)
/TXD: J5.3, U4.16 (TXD)
/Vin: C1.1, D1.1 (K), Q1.2 (S), R2.2, U1.5 (VIN)
/XIN: R13.1, U3.5 (PF0)
/XOUT: R14.1, U3.6 (PF1)
CAN_LED: D7.2 (A), U3.39 (PB3)
CAN_RX: U3.32 (PA11), U6.4 (R)
CAN_TERM: U3.31 (PA10), U7.4 (E)
CAN_TX: U3.33 (PA12), U6.1 (D)
CH_PD: R15.2, U4.3 (CH_PD)
DAC: U3.14 (PA4), U5.3 (+)
ERROR_LED: D9.2 (A), U3.41 (PB5)
ESP_RESET: C5.1, D4.1 (K), R5.2, SW1.2, U4.1 (REST)
GND: C1.2, C2.2, C4.2, C5.2, C6.2, C7.2, C8.2, C11.2, C12.1, C13.2, C14.2, C15.1, C18.1, D2.2 (A), D3.2 (A), D11.3 (A), J1.2, J4.5, J5.5, J7.3, NT1.1, R1.2, R4.1, R7.1, R10.1, R11.1, R12.1, R17.2, R21.2, R23.1, R24.1, R25.1, SW1.1, SW2.1, U1.2 (GND), U2.2 (GND), U3.23 (VSS), U3.35 (VSS), U3.47 (VSS), U4.9 (GND), U6.2 (GND), U7.3 (GND), Y1.2
GNDA: C10.2, C16.2, C17.2, J6.2, NT1.2, R19.2, U3.8 (VSSA), U5.2 (V-)
GPIO0: R22.2, SW2.2, U4.12 (GPIO0)
GPIO2: R9.2, U4.11 (GPIO2)
MISO: U3.27 (PB14), U4.6 (GPIO12)
MOSI: U3.28 (PB15), U4.7 (GPIO13)
unnamed: C3.1, D3.1 (K), L1.1, U1.6 (SW)
unnamed: C3.2, U1.1 (BST)
unnamed: C9.2, R6.2, R7.2, U1.3 (FB)
unnamed: D1.2 (A), Q1.1 (G), R1.1
unnamed: D2.1 (K), R2.1, R3.2, U1.4 (EN)
unnamed: D6.1 (K), J5.4
unnamed: D7.1 (K), R23.2
unnamed: D8.1 (K), R24.2
unnamed: D9.1 (K), R25.2
unnamed: D10.1 (K), R22.1
unnamed: J1.1, Q1.3 (D)
unnamed: J6.1, R20.1, U5.1
unnamed: JP2.1, R8.2
unnamed: R3.1, R4.2
unnamed: R13.2, Y1.1
unnamed: R14.2, Y1.3
unnamed: R18.1, R20.2, U5.4 (-)
unnamed: R18.2, R19.1
unnamed: R21.1, U6.8 (Rs)
unnamed: R26.2, U7.2 (Z)
unnamed: TP1.1, U3.38 (PA15)
SCLK: U3.26 (PB13), U4.5 (GPIO14)
SPI_LED: D8.2 (A), U3.40 (PB4)
STM_CS: R17.1, U3.29 (PA8), U4.10 (GPIO15)
STM_RDY: U3.25 (PB12), U4.13 (GPIO4)
STM_RESET: C12.2, D4.2 (A), J4.3, R16.2, R27.1, U3.7 (NRST)
VDDA: C10.1, FB1.2, U3.9 (VDDA)
V_B0: R12.2, U3.18 (PB0)
V_B1: R11.2, U3.19 (PB1)
V_B2: R10.2, U3.20 (PB2)

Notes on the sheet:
TC2030-IDC-NL
CAN Interface
Vfb = Vout * Rg/(Rf+Rg) Rf = 124k for optimal response Vfb = 0.794 typ
This may be used in the future to indicate the presence of a 16bit DAC or 4 channel output DAC. Also other minor PCB mods as requred. Table will indicate version features when they have been implemented.
5V5 DC-DC Converter
ERC Happy Area
ESP8277 WiFi Interface
Power Input with Polarity Protection
Test TPS560430 as drop in replacment for BL9342
V_B2
CAN Interface HW Version Indicator
EN Pin Vmax = 5V
GPIO Internal Pullup
G = 5.0/3.3 G = 1 + (68k/[120k + 12k])
OPA330 Bypass Capacitors
STM32F302 Power Distribution and Bypass
V_B0
V_B1
Analog Output Amplification
Reset Circuitry
STM32F302 CAN Interface
Indicator LEDs
Version
3V3 LDO
STM32F302 IO is 5V tolerent on CAN_TX and CAN_RX GPIO. Voltage Selector added to evauate lower cost 5V xcever ICs
Mechanical
STM 12bit DAC

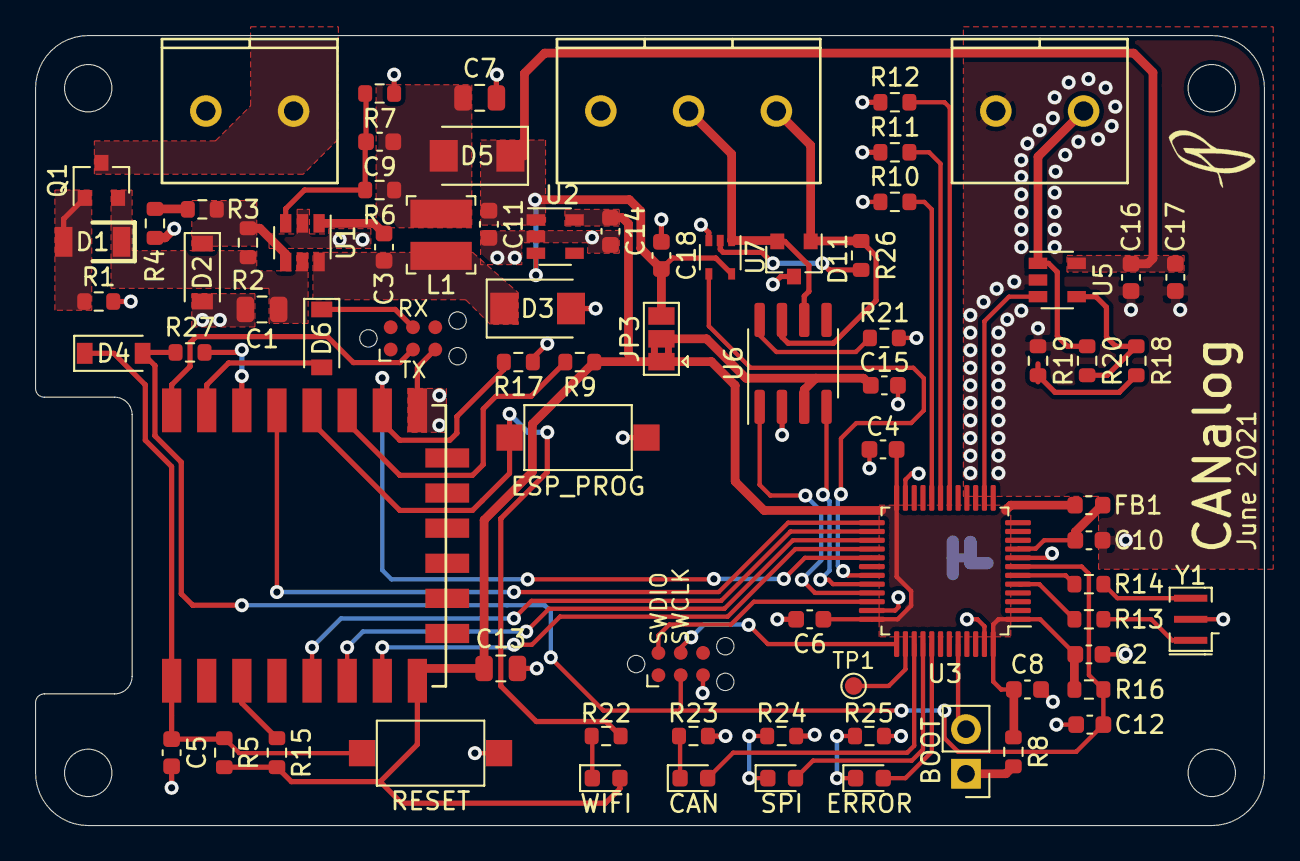
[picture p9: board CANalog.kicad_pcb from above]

Board: 2 copper layers, 70.0 x 45.0 mm, 82 parts (1 on the bottom side), 59 nets.

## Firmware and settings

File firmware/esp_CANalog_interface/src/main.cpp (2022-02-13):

#include <Arduino.h>
#include <DNSServer.h>
#include <ESP_EEPROM.h>
#include <TaskScheduler.h>

/* ESP8266 WiFi Includes ----------------------------------------------------- */
#include <ESP8266WiFi.h>
#include <ESPAsyncTCP.h>
#include <ESPAsyncWebServer.h>
#include <AsyncElegantOTA.h>
#include <ArduinoJson.h>

/* Local Libraries ----------------------------------------------------------- */
#include "spi_master.h"
#include "can_signal.h"

/* Raw String Literals for Webpages ------------------------------------------ */
#include "about.html.h"
#include "about.js.h"
#include "analog.html.h"
#include "analog.js.h"
#include "Chart.min.js.h"
#include "index.html.h"
#include "index.js.h"
#include "pgnid.html.h"
#include "pgnid.js.h"
#include "saved_nok.html.h"
#include "saved_ok.html.h"
#include "style.css.h"
#include "view.html.h"
#include "view.js.h"

/* Version Info -------------------------------------------------------------- */
#define DEVICE_NAME				  "CANalog"
#define SERVER_ADDRESS      "www.canalog.io"
/* Version should be interpreted as: (MAIN).(TOPIC).(FUNCTION).(BUGFIX)
 * 		MAIN marks major milestones of the project such as release
 * 		TOPIC marks the introduction of a new functionality or major changes
 * 		FUNCTION marks introduction of new functionality and aim to advance the current TOPIC
 * 		BUGFIX marks very minor updates such as bug fix, optimization, or text edit
 */
#define FW_VERSION				  "V1.0.3.2"
char stm32_fw_version[9];                 /* string that stores fw version from stm32 */
char stm32_hw_version[5];                 /* string that stores hw version from stm32 */

/* Private define ------------------------------------------------------------ */
#define DEBUG_MESSAGES      1             /* set to 1 to enable serial print messages */

#define WIFI_LED_PIN        0             /* clients connected indicator */
#define STM32_RESET_PIN     5             /* esp pin used to reset STM32 on startup */
#define STM32_RDY_PIN       4             /* STM32 will pull this pin low when it is ready to receive SPI data */

/* WiFi Settings ------------------------------------------------------------- */
#define SSID_LEN            32            /* sources suggest SSID length has a max of 32 characters */
String ssid = DEVICE_NAME + String(" ");  /* first part of ssid, will append device sn to end */
IPAddress apIP(192, 168, 4, 1);
IPAddress subnet(255,255,255,0);

const byte DNS_PORT = 53;
DNSServer dnsServer;

AsyncWebServer server(80);
AsyncWebSocket ws("/ws");
StaticJsonDocument<1028> wsData;

#define WS_TRANSMIT_RATE_ms 1000

/* Private macro ------------------------------------------------------------- */
#if DEBUG_MESSAGES
#define debugLog(x) 	Serial.print(x)
#define debugLogln(x)	Serial.println(x)
#else
#define debugLog(x)
#define debugLogln(x)
#endif

/* Private variables --------------------------------------------------------- */
Signal_Handle_t can;                      /* data used on webpages and passed between esp and STM32 */
ESPMaster spiMaster(SS, STM32_RDY_PIN);   /* ESP master SPI mode */

/* Private function prototypes ----------------------------------------------- */

/* Webserver Handles --------------------------------------------------------- */
void handleRoot(AsyncWebServerRequest *request);
void handleSave(AsyncWebServerRequest *request);
void handleAnalog(AsyncWebServerRequest *request);
void handleView(AsyncWebServerRequest *request);
void handlePGNtoID(AsyncWebServerRequest *request);
void handleAbout(AsyncWebServerRequest *request);
void handleIndexJavascript(AsyncWebServerRequest *request);
void handleAnalogJavascript(AsyncWebServerRequest *request);
void handleViewJavascript(AsyncWebServerRequest *request);
void handlePGNtoIDJavascript(AsyncWebServerRequest *request);
void handleAboutJavascript(AsyncWebServerRequest *request);
void handleChartJavascript(AsyncWebServerRequest *request);
void handleStyle(AsyncWebServerRequest *request);
void handleData(AsyncWebServerRequest *request);
void handleInfo(AsyncWebServerRequest *request);
void handleNotFound(AsyncWebServerRequest *request);
void handleInvalidRequest(AsyncWebServerRequest *request);
void onWsEvent(AsyncWebSocket * server, 
               AsyncWebSocketClient * client, 
               AwsEventType type, 
               void * arg, 
               uint8_t *data, 
               size_t len);
void wsReceiveParse(uint8_t *data, size_t len);
void wsStream();

/* Task Scheduler ------------------------------------------------------------ */
Scheduler runner;
Task wsTask(WS_TRANSMIT_RATE_ms, TASK_FOREVER, &wsStream);

/* Setup --------------------------------------------------------------------- */
void setup(void){
  /* start serial for debugging ---------------------------------------------- */
  Serial.begin(115200);
  Serial.println("\n\r");

  pinMode(WIFI_LED_PIN, OUTPUT);
  digitalWrite(WIFI_LED_PIN, HIGH);

  /* setup task scheduler ---------------------------------------------------- */
	runner.init();

  /* start SPI master -------------------------------------------------------- */
  spiMaster.begin();

  pinMode(STM32_RESET_PIN, OUTPUT);   /* reset STM32 to avoid error states */
  digitalWrite(STM32_RESET_PIN, LOW);
  delay(1000);
  digitalWrite(STM32_RESET_PIN, HIGH);
  delay(10000);                       /* wait for STM32 to startup */

  /* get data from STM32 so we can use sn to set the SSID -------------------- */
  spiMaster.read(SPI_GET_FW_VERSION, (uint8_t*) stm32_fw_version, sizeof(stm32_fw_version));
  Serial.print("STM32 FW: ");
  Serial.println(String(stm32_fw_version));

  spiMaster.read(SPI_GET_HW_VERSION, (uint8_t*) stm32_hw_version, sizeof(stm32_hw_version));
  Serial.print("STM32 HW: ");
  Serial.println(String(stm32_hw_version));


  /* assemble SSID with SN from STM32 for unique SSID per device -------------*/
  uint32_t sn;
  spiMaster.read(SPI_GET_SN, (uint8_t*) &sn, sizeof(sn));
  ssid += String(sn, HEX);

  /* setup EEPROM ------------------------------------------------------------*/
  EEPROM.begin(sizeof(Signal_Handle_t));

  /* Check if the EEPROM contains valid data from another run */
  if(EEPROM.percentUsed()>=0) {         /* valid data from previous run */
    EEPROM.get(0, can);                 /* get data to update Signal_Handle_t */
    Serial.println("EEPROM has data from a previous run.");
    Serial.print(EEPROM.percentUsed());
    Serial.println("% of ESP flash space currently used");

    spiMaster.write((uint8_t *) &can, sizeof(Signal_Handle_t)); /* send data from EEPROM to STM32 */
  } else {
    Serial.println("EEPROM size changed - EEPROM data zeroed - commit() to make permanent");  
  }

  /* start up WiFi Server ----------------------------------------------------*/
  Serial.print("Setting AP configuration ... ");
  Serial.println(WiFi.softAPConfig(apIP, apIP, subnet) ? "Ready" : "Failed!");

  Serial.print("Setting AP ... ");
  Serial.println(WiFi.softAP(ssid) ? "Ready" : "Failed!");

  Serial.print("AP IP address = ");
  Serial.println(WiFi.softAPIP());

  /* DNS Server --------------------------------------------------------------*/
  /* modify TTL associated  with the domain name (in seconds), default is 60 seconds */
  dnsServer.setTTL(300);
  /* set which return code will be used for all other domains (e.g. sending
   *  ServerFailure instead of NonExistentDomain will reduce number of queries sent by clients)
   *  default is DNSReplyCode::NonExistentDomain */
  dnsServer.setErrorReplyCode(DNSReplyCode::ServerFailure);

  // start DNS server for a specific domain name
  dnsServer.start(DNS_PORT, SERVER_ADDRESS, apIP);

  /* Websocket ---------------------------------------------------------------*/
  ws.onEvent(onWsEvent);
  server.addHandler(&ws);

  /* server page request handles ---------------------------------------------*/
  server.on("/", HTTP_GET, handleRoot);           /* Call the 'handleRoot' function when a client requests URI "/" */
  server.on("/index.html", HTTP_GET, handleRoot); /* Call the 'handleRoot' function when a client requests URI "/index" */
  server.on("/save", HTTP_POST, handleSave);      /* Call the 'handleSave' function when a POST request is made to URI "/save" */
  server.on("/analog.html", HTTP_GET, handleAnalog);
  server.on("/view.html", HTTP_GET, handleView);
  server.on("/pgnid.html", HTTP_GET, handlePGNtoID);
  server.on("/about.html", HTTP_GET, handleAbout);
  server.on("/index.js", handleIndexJavascript);  /* javascript */
  server.on("/analog.js", handleAnalogJavascript);
  server.on("/view.js", handleViewJavascript);
  server.on("/pgnid.js", handlePGNtoIDJavascript);
  server.on("/about.js", handleAboutJavascript);
  server.on("/Chart.min.js", handleChartJavascript);
  server.on("/style.css", handleStyle);           /* styles */
  server.on("/data.txt", handleData);
  server.on("/info.txt", handleInfo);
  server.onNotFound(handleNotFound);              /* When a client requests an unknown URI call function "handleNotFound" */

  AsyncElegantOTA.begin(&server);                 /* Start OTA update server */
  server.begin();                                 /* Actually start the server */
  Serial.println("HTTP server started");
}

/* Main Loop ----------------------------------------------------------------- */
void loop(void){
  dnsServer.processNextRequest();
  ws.cleanupClients();
  runner.execute();

  if (WiFi.softAPgetStationNum() > 0){
    digitalWrite(WIFI_LED_PIN, LOW);
  } else {
    digitalWrite(WIFI_LED_PIN, HIGH);
  }
}

/* Web Server Handle Functions ----------------------------------------------- */
void handleRoot(AsyncWebServerRequest *request) {
  request->send_P(200, "text/html", PAGE_index_HTML);
}

void handleSave(AsyncWebServerRequest *request) {
  can.can_baud    = request->arg("can_baud").toInt();
  can.can_type    = request->arg("can_id_bit_len").toInt();
  can.can_id      = strtoul(request->arg("can_id").c_str(), NULL, 16);
  can.start_bit   = request->arg("can_signal_start_bit").toInt();
  can.bit_len     = request->arg("can_signal_bit_len").toInt();
  can.endianness  = request->arg("can_endianness").toInt();
  can.max         = request->arg("can_signal_max").toInt();
  can.min         = request->arg("can_signal_min").toInt();
  can.term        = request->arg("term").toInt();

  /* save data to EEPROM */
  EEPROM.put(0, can);
  boolean ok = EEPROM.commit();
  Serial.println((ok) ? "Commit OK" : "Commit failed");

  /* send data to STM32 */
  spiMaster.write((uint8_t *) &can, sizeof(Signal_Handle_t));
  printData(&can);

  /* check to make sure data was received */
  Signal_Handle_t can_on_stm32;
  spiMaster.read((uint8_t *) &can_on_stm32, sizeof(Signal_Handle_t));
  printData(&can_on_stm32);

  if (signal_struct_cmp(&can, &can_on_stm32) == SIGNAL_STRUCTS_ARE_EQUAL) {
    request->send_P(200, "text/html", PAGE_saved_ok_HTML); // data transfer is good
  } else {
    request->send_P(200, "text/html", PAGE_saved_nok_HTML); // data transfer is good
  }
}

void handleAnalog(AsyncWebServerRequest *request) {
  request->send_P(200, "text/html", PAGE_analog_HTML);
}

void handleView(AsyncWebServerRequest *request) { 
  request->send_P(200, "text/html", PAGE_view_HTML);
}

void handlePGNtoID(AsyncWebServerRequest *request) { 
  request->send_P(200, "text/html", PAGE_pgnid_HTML);
}

void handleAbout(AsyncWebServerRequest *request) {
  request->send_P(200, "text/html", PAGE_about_HTML);
}

void handleIndexJavascript(AsyncWebServerRequest *request) {
  request->send_P(200, "application/javascript", PAGE_index_JS);
}

void handleAnalogJavascript(AsyncWebServerRequest *request) {
  request->send_P(200, "application/javascript", PAGE_analog_JS);
}

void handleViewJavascript(AsyncWebServerRequest *request) {
  request->send_P(200, "application/javascript", PAGE_view_JS);
}

void handlePGNtoIDJavascript(AsyncWebServerRequest *request) {
  request->send_P(200, "application/javascript", PAGE_pgnid_JS);
}

void handleAboutJavascript(AsyncWebServerRequest *request) {
  request->send_P(200, "application/javascript", PAGE_about_JS);
}

void handleChartJavascript(AsyncWebServerRequest *request) {
  request->send_P(200, "application/javascript", PAGE_chart_JS);
}

void handleStyle(AsyncWebServerRequest *request) {
  request->send_P(200, "text/css", PAGE_style_CSS);
}

void handleData(AsyncWebServerRequest *request) {
  /* read data */
  spiMaster.read((uint8_t *) &can, sizeof(Signal_Handle_t));

  StaticJsonDocument<192> data;

  data["baud"] = can.can_baud;
  data["type"] = can.can_type;
  data["id"] = String(can.can_id, HEX);
  data["start_bit"] = can.start_bit;
  data["bit_len"] = can.bit_len;
  data["endianness"] = can.endianness;
  data["max"] = can.max;
  data["min"] = can.min;
  data["term"] = can.term;
  data["value"] = can.value;
  data["dac_out"] = can.dac_out;

  String json;
  serializeJson(data, json);

  request->send(200, "application/json", json);
}

void handleInfo(AsyncWebServerRequest *request) {
  StaticJsonDocument<192> info;

  info["esp_fw"] = FW_VERSION;
  info["stm_fw"] = stm32_fw_version;
  info["stm_hw"] = stm32_hw_version;

  String json;
  serializeJson(info, json);

  request->send(200, "application/json", json);
}

void handleNotFound(AsyncWebServerRequest *request){
  request->send(404, "text/plain", "404: Not found");               // Send HTTP status 404 (Not Found) when there's no handler for the URI in the request
}

void handleInvalidRequest(AsyncWebServerRequest *request) {
  request->send(400, "text/plain", "400: Invalid Request");         // The request is invalid, so send HTTP status 400
}

void onWsEvent(AsyncWebSocket *server, AsyncWebSocketClient *client, 
               AwsEventType type, void *arg, uint8_t *data, size_t len) {
	
	AwsFrameInfo * info = (AwsFrameInfo*)arg;
    switch(type) {
      case WS_EVT_CONNECT:
        /* client connected */
        Serial.printf("ws[%s][%u] connect\n", server->url(), client->id());
        client->printf("Hello Client %u :)", client->id());
        client->ping();
        runner.addTask(wsTask);
        wsTask.enable();
        break;
      case WS_EVT_DISCONNECT:
        /* client disconnected */
        Serial.printf("ws[%s][%u] disconnect\n", server->url(), client->id());
        wsTask.disable();
        runner.deleteTask(wsTask);
        break;
      case WS_EVT_ERROR:
        /* error was received from the other end */
        Serial.printf("ws[%s][%u] error(%u): %s\n", server->url(), client->id(), *((uint16_t*)arg), (char*)data);
        break;
      case WS_EVT_PONG:
        /* pong message was received (in response to a ping request maybe) */
        Serial.printf("ws[%s][%u] pong[%u]: %s\n", server->url(), client->id(), len, (len)?(char*)data:"");
        break;
      case WS_EVT_DATA:
        /* data packet */
        if(info->final && info->index == 0 && info->len == len) {
          //the whole message is in a single frame and we got all of it's data
          Serial.printf("ws[%s][%u] %s-message[%llu]: ", 
                server->url(), client->id(), (info->opcode == WS_TEXT)?"text":"binary", info->len);
          if(info->opcode == WS_TEXT) {
            data[len] = 0;
            Serial.printf("%s\n", (char*)data);
            wsReceiveParse(data, info->len);
          } else {
            for(size_t i=0; i < info->len; i++){
              Serial.printf("%02x ", data[i]);
            }
            Serial.printf("\n");
          }
          if(info->opcode == WS_TEXT)
            client->text("I got your text message");
          else
            client->binary("I got your binary message");
        } else {
          //message is comprised of multiple frames or the frame is split into multiple packets
          if(info->index == 0){
            if(info->num == 0)
            Serial.printf("ws[%s][%u] %s-message start\n", server->url(), client->id(), (info->message_opcode == WS_TEXT)?"text":"binary");
            Serial.printf("ws[%s][%u] frame[%u] start[%llu]\n", server->url(), client->id(), info->num, info->len);
          }

          Serial.printf("ws[%s][%u] frame[%u] %s[%llu - %llu]: ", 
                server->url(), client->id(), info->num, 
                (info->message_opcode == WS_TEXT)?"text":"binary", info->index, info->index + len);
          if(info->message_opcode == WS_TEXT){
            data[len] = 0;
            Serial.printf("%s\n", (char*)data);
          } else {
            for(size_t i=0; i < len; i++){
              Serial.printf("%02x ", data[i]);
            }
            Serial.printf("\n");
          }

          if((info->index + len) == info->len){
            Serial.printf("ws[%s][%u] frame[%u] end[%llu]\n", server->url(), client->id(), info->num, info->len);
            if(info->final) {
              Serial.printf("ws[%s][%u] %s-message end\n", 
                    server->url(), client->id(), (info->message_opcode == WS_TEXT)?"text":"binary");
              if(info->message_opcode == WS_TEXT)
                client->text("I got your text message");
              else
                client->binary("I got your binary message");
            }
          }
        }
        break;
      default:
        break;
	}
}

void wsReceiveParse(uint8_t *data, size_t len) {
	/* get data from JSON */
	DeserializationError error = deserializeJson(wsData, data, len);

	if (error) {
		debugLog("deserializeJason() failed: ");
		debugLogln(error.f_str());
	}

  uint16_t dac_out = 0;

	switch (wsData["action"].as<uint8_t>()) {
    case WS_ACTION_SET_DAC:
      dac_out = wsData["dac_out"].as<uint16_t>();
      debugLogln(dac_out);
      spiMaster.write(SPI_SET_DAC_VALUE, (uint8_t *) &dac_out, sizeof(dac_out));
      
      break;
    case WS_ACTION_PAUSE_STREAM:
      wsTask.disable();
      break;
    case WS_ACTION_RESUME_STREAM:
      wsTask.enable();
    default:
      break;
	}
}

void wsStream() {
  spiMaster.read(SPI_GET_CAN_SIGNAL, (uint8_t *) &can.value, sizeof(can.value));
  delayMicroseconds(50);
  spiMaster.read(SPI_GET_DAC_VALUE, (uint8_t *) &can.dac_out, sizeof(can.dac_out));
  delayMicroseconds(50);
  spiMaster.read(SPI_GET_CAN_FRAME, can.frame, sizeof(can.frame));

  StaticJsonDocument<128> data;
  
  data["value"] = can.value;
  data["dac"] = can.dac_out;
  data["sMax"] = can.max;
  data["sMin"] = can.min;
  
  String frame;
  for (uint8_t i=0; i<sizeof(can.frame); i++) {
    frame += (can.frame[i] < 16 ? "0": "") + String(can.frame[i], HEX); // add leading zero
  }

  data["frame"] = frame;

  String json;
  serializeJson(data, json);

  ws.textAll(json.c_str(), json.length());
}

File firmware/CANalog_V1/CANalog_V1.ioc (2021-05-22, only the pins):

Mcu.UserName=STM32F302C8Tx
PB0.GPIO_Label=V_B0
PB13.Signal=SPI2_SCK
PB15.Signal=SPI2_MOSI
PA15.GPIO_Label=TP1
PA12.Signal=CAN_TX
PB2.Signal=GPIO_Input
PB12.GPIO_Label=SPI2_RDY
PB1.GPIO_Label=V_B1
PA10.GPIO_Label=CAN_TERM
PA8.Signal=GPIO_Input
PB1.Signal=GPIO_Input
PA10.Signal=GPIO_Output
PA15.Signal=GPIO_Output
PB5.GPIO_Label=ERROR_LED
PB4.Signal=GPIO_Output
PB3.GPIO_Label=CAN_LED
PA13.Signal=SYS_JTMS-SWDIO
PA8.GPIO_Label=SPI2_CS
PB14.Signal=SPI2_MISO
PB4.GPIO_Label=SPI_LED
PB3.Signal=GPIO_Output
PA4.Signal=COMP_DAC1_group
PB5.Signal=GPIO_Output
PA11.Signal=CAN_RX
PA14.Signal=SYS_JTCK-SWCLK
PB2.GPIO_Label=V_B2
PB0.Signal=GPIO_Input
PB12.Signal=GPIO_Output

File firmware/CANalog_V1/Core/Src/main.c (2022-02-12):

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
/* Includes ------------------------------------------------------------------*/
#include "main.h"
#include "can.h"
#include "dac.h"
#include "spi.h"
#include "tim.h"
#include "gpio.h"

/* USER CODE BEGIN Includes */
#include "string.h"
#include "can_signal.h"
#include "can_bit_timing.h"

/* USER CODE END Includes */

/* USER CODE BEGIN PTD */
#define DEVICE_NAME				"CANalog"
/* Version should be interpreted as: (MAIN).(TOPIC).(FUNCTION).(BUGFIX)
 * 		MAIN marks major milestones of the project such as release
 * 		TOPIC marks the introduction of a new functionality or major changes
 * 		FUNCTION marks introduction of new functionality and aim to advance the current TOPIC
 * 		BUGFIX marks very minor updates such as bug fix, optimization, or text edit
 */
#define HW_VERSION				"V1.0"
#define FW_VERSION				"V1.0.2.2"

/* USER CODE END PTD */


/* USER CODE BEGIN PV */
SPI_HandleTypeDef hspi2;
DAC_HandleTypeDef hdac;
CAN_HandleTypeDef hcan;
TIM_HandleTypeDef htim16;

CAN_FilterTypeDef canFilter;
CAN_RxHeaderTypeDef canRxHeader;
uint8_t canRxBuffer[8];

Signal_Handle_t signal;

uint32_t sn;

/* USER CODE END PV */

void SystemClock_Config(void);
/* USER CODE BEGIN PFP */
void can_filter_init(CAN_HandleTypeDef *hcan, CAN_FilterTypeDef *canFilter);
void HAL_TIM_PeriodElapsedCallback(TIM_HandleTypeDef *htim);
void can_led_touch();

/* USER CODE END PFP */

/**
 * @brief  The application entry point.
 * @retval int
 */
int main(void) {
	/* MCU Configuration--------------------------------------------------------*/

	/* Reset of all peripherals, Initializes the Flash interface and the Systick. */
	HAL_Init();

	/* Configure the system clock */
	SystemClock_Config();

	/* Initialize all configured peripherals */
	MX_GPIO_Init();
	MX_CAN_Init();
	MX_DAC_Init();
	MX_SPI2_Init();
	MX_TIM16_Init();
	/* USER CODE BEGIN 2 */
	sn = calc_sn();

	signal_init(&signal); /* initialize signal to default values */

	can_filter_init(&hcan, &canFilter);

	if (HAL_CAN_Start(&hcan) != HAL_OK) {
		Error_Handler();
	}

	/* set DAC */
	HAL_DAC_SetValue(&hdac, DAC1_CHANNEL_1, DAC_ALIGN_12B_R, 0);
	HAL_DAC_Start(&hdac, DAC1_CHANNEL_1);

	/* USER CODE END 2 */

	/* Infinite loop */
	/* USER CODE BEGIN WHILE */
	while (1) {
		/* USER CODE END WHILE */

		/* USER CODE BEGIN 3 */
		/* SPI Check ---------------------------------------------------------*/
		if (HAL_GPIO_ReadPin(SPI2_CS_GPIO_Port, SPI2_CS_Pin) == 0) { /* esp8266 wants to talk */
			HAL_GPIO_WritePin(SPI_LED_GPIO_Port, SPI_LED_Pin, GPIO_PIN_SET);
			HAL_GPIO_WritePin(SPI2_RDY_GPIO_Port, SPI2_RDY_Pin, GPIO_PIN_RESET); /* signal to esp8266 we are ready to talk */

			uint8_t command_bit = 0;
			if (HAL_SPI_Receive(&hspi2, &command_bit, sizeof(command_bit), 2) != HAL_OK) {
				Error_Handler();
			}

			switch (command_bit) {
			case SPI_SIGNAL_SEND: /* esp is requesting parameters */
				if (HAL_SPI_Transmit(&hspi2, (uint8_t*) &signal, sizeof(Signal_Handle_t), 5) != HAL_OK) {
					Error_Handler();
				}
				break;
			case SPI_SIGNAL_RECEIVE: /* esp is sending new parameters*/
				if (HAL_SPI_Receive(&hspi2, (uint8_t*) &signal, sizeof(Signal_Handle_t), 5) != HAL_OK) {
					Error_Handler();
				}

				signal_update(&signal); /* recalculate signal values */
				/* restart CAN interface with new baud rate -----------------------*/
				if (HAL_CAN_Stop(&hcan) != HAL_OK) {
					Error_Handler();
				}
				/* stop CAN and deinit so we can configure it */
				if (HAL_CAN_DeInit(&hcan) != HAL_OK) {
					Error_Handler();
				}
				/* set new bit timing */
				can_set_bit_timing(&signal, &hcan);
				/* reinitialize CAN */
				if (HAL_CAN_Init(&hcan) != HAL_OK) {
					Error_Handler();
				}
				/* restart can */
				if (HAL_CAN_Start(&hcan) != HAL_OK) {
					Error_Handler();
				}
				/* set DAC to zero */
				HAL_DAC_SetValue(&hdac, DAC_CHANNEL_1, DAC_ALIGN_12B_R, 0);
				break;
			case SPI_SEND_SN:
				if (HAL_SPI_Transmit(&hspi2, (uint8_t*) &sn, sizeof(sn), 5) != HAL_OK) {
					Error_Handler();
				}
				break;
			case SPI_SEND_FW_VERSION:
				if (HAL_SPI_Transmit(&hspi2, (uint8_t*) FW_VERSION, sizeof(FW_VERSION), 5) != HAL_OK) {
					Error_Handler();
				}
				break;
			case SPI_SEND_HW_VERSION:
				if (HAL_SPI_Transmit(&hspi2, (uint8_t*) HW_VERSION, sizeof(HW_VERSION), 5) != HAL_OK) {
					Error_Handler();
				}
				break;
			case SPI_SEND_CAN_SIGNAL:
				if (HAL_SPI_Transmit(&hspi2, (uint8_t*) &signal.value, sizeof(signal.value), 5) != HAL_OK) {
					Error_Handler();
				}
				break;
			case SPI_SEND_DAC_VALUE:
				if (HAL_SPI_Transmit(&hspi2, (uint8_t*) &signal.dac_out, sizeof(signal.dac_out), 5) != HAL_OK) {
					Error_Handler();
				}
				break;
			case SPI_SEND_CAN_FRAME:
				if (HAL_SPI_Transmit(&hspi2, (uint8_t*) &signal.frame, sizeof(signal.frame), 5) != HAL_OK) {
					Error_Handler();
				}
				break;
			case SPI_SET_DAC_VALUE:
				if (HAL_SPI_Receive(&hspi2, (uint8_t*) &signal.dac_out, sizeof(signal.dac_out), 5) != HAL_OK) {
					Error_Handler();
				}
				HAL_DAC_SetValue(&hdac, DAC_CHANNEL_1, DAC_ALIGN_12B_R, signal.dac_out);
				break;
			default:
				break;
			}

			HAL_GPIO_WritePin(SPI2_RDY_GPIO_Port, SPI2_RDY_Pin, GPIO_PIN_SET); /* return ready pin to high */

			while (HAL_GPIO_ReadPin(SPI2_CS_GPIO_Port, SPI2_CS_Pin) == 0) {
				; /* loop until esp8266 pulls CS high */
			}
			HAL_GPIO_WritePin(SPI_LED_GPIO_Port, SPI_LED_Pin, GPIO_PIN_RESET);
		}

		/* CAN ---------------------------------------------------------------*/
		if (HAL_CAN_GetRxFifoFillLevel(&hcan, CAN_RX_FIFO0) != 0) {
			if (HAL_CAN_GetRxMessage(&hcan, CAN_RX_FIFO0, &canRxHeader, canRxBuffer) != HAL_OK) {
				Error_Handler();
			} // end HAL_CAN_GetRxMessage

			switch (signal.can_type) {
			case ID_TYPE_11BIT:
				if (canRxHeader.StdId == signal.can_id) {
					/* copy canRxBuffer into signal */
					memcpy(signal.frame, canRxBuffer, sizeof(signal.frame));

					signal_calc(&signal);
					HAL_DAC_SetValue(&hdac, DAC_CHANNEL_1, DAC_ALIGN_12B_R, signal.dac_out);
					can_led_touch();
				}
				break;
			case ID_TYPE_29BIT:
				if (canRxHeader.ExtId == signal.can_id) {
					/* copy canRxBuffer into signal */
					memcpy(signal.frame, canRxBuffer, sizeof(signal.frame));

					signal_calc(&signal);
					HAL_DAC_SetValue(&hdac, DAC_CHANNEL_1, DAC_ALIGN_12B_R, signal.dac_out);
					can_led_touch();
				}
				break;
			default:
				break;
			} // end switch(signal.can_type)
		} // end HAL_CAN_GetRxFifoFillLevel
	}
	/* USER CODE END 3 */
}

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
/* USER CODE BEGIN 4 */
void can_filter_init(CAN_HandleTypeDef *hcan, CAN_FilterTypeDef *canFilter) {
	canFilter->FilterBank = 0;
	canFilter->FilterMode = CAN_FILTERMODE_IDMASK;
	canFilter->FilterScale = CAN_FILTERSCALE_32BIT;
	canFilter->FilterIdHigh = 0;
	canFilter->FilterIdLow = 0;
	canFilter->FilterMaskIdHigh = 0;
	canFilter->FilterMaskIdLow = 0;
	canFilter->FilterFIFOAssignment = CAN_RX_FIFO0;
	canFilter->FilterActivation = ENABLE;

	if (HAL_CAN_ConfigFilter(hcan, canFilter) != HAL_OK) {
		Error_Handler();
	}
}
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

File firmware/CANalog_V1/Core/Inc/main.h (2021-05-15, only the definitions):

#define V_B0_Pin GPIO_PIN_0
#define V_B0_GPIO_Port GPIOB
#define V_B1_Pin GPIO_PIN_1
#define V_B1_GPIO_Port GPIOB
#define V_B2_Pin GPIO_PIN_2
#define V_B2_GPIO_Port GPIOB
#define SPI2_RDY_Pin GPIO_PIN_12
#define SPI2_RDY_GPIO_Port GPIOB
#define SPI2_CS_Pin GPIO_PIN_8
#define SPI2_CS_GPIO_Port GPIOA
#define CAN_TERM_Pin GPIO_PIN_10
#define CAN_TERM_GPIO_Port GPIOA
#define TP1_Pin GPIO_PIN_15
#define TP1_GPIO_Port GPIOA
#define CAN_LED_Pin GPIO_PIN_3
#define CAN_LED_GPIO_Port GPIOB
#define SPI_LED_Pin GPIO_PIN_4
#define SPI_LED_GPIO_Port GPIOB
#define ERROR_LED_Pin GPIO_PIN_5
#define ERROR_LED_GPIO_Port GPIOB

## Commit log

2021-01-11 start shematic
    [CANalog_nucleo.kicad_pcb, CANalog_nucleo.sch]
2021-01-23 start schema
    [CANalog_nucleo.sch]
2021-01-24 schematic done
    [CANalog_nucleo.sch]
2021-01-24 quickand dirty prototype
    [CANalog_nucleo.kicad_pcb, CANalog_nucleo.sch]
2021-01-24 generate gerbers
    [CANalog_nucleo-B_Cu.gbr, CANalog_nucleo-B_Mask.gbr, CANalog_nucleo-B_Paste.gbr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]
2021-01-24 generate ibom
    [CANalog_nucleo.kicad_pcb]
2021-01-26 use correct device name
    [main.cpp]
2021-01-28 play with UART command parsing, needs help
2021-01-31 uart command parser working
2021-02-01 stuff and things
    [startup_parameters.txt]
2021-02-02 uart issues
2021-02-02 working uart communication but esp double sends get commands
2021-02-04 fixed can to analog
    [main.c]
2021-02-06 signal in frame calulations
2021-02-07 baud switching, not tested much
2021-02-07 big endian bit shift fix
    [can_signal.c, can_signal.h]
2021-02-07 value send timout and retry error detection
    [main.cpp]
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2021-02-15 add logic probe data and setup
2021-02-15 implement SPI interface with STM32
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2021-02-19 redo stm32 project file
2021-02-19 spi polling with ready pin
2021-02-19 add spi rdy pin
2021-02-20 spi error handling
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2021-02-21 update schematic
    [CANalog_nucleo.sch]
2021-02-22 start new pcb layout
    [CANalog_nucleo.kicad_pcb, CANalog_nucleo.sch]
2021-02-24 layout getting there
    [CANalog_nucleo.kicad_pcb, CANalog_nucleo.sch]
2021-03-02 layout done
    [CANalog_nucleo.kicad_pcb]
2021-03-07 upgrade to Async webserver to support future use of websockets
    [startup_parameters.txt]
2021-03-08 update ibom
    [CANalog_nucleo.kicad_pcb]
2021-03-10 add 10k pulldown on GPIO15 of esp
    [CANalog_nucleo.sch]
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2021-03-20 remove signal page, combined with frame page
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2021-03-20 remove analog and frame display webpage
2021-03-22 change command verb to reflect stm32 spi action
2021-03-22 change spi command to reflect data handled
2021-03-24 pull spi cs pin high on timeout to release stm32
2021-03-25 can frame websocket streaming
2021-03-26 update to new circuitry, work in progress
    [CANalog.sch]
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2021-03-27 request SN spi command
2021-03-27 fix json data stream bug of frame not sending enough characters
    remeber for HEX data to a string for a leading zero use < 16 not 10!
    was stuck on this for hours!!!!
    [main.cpp]
2021-03-27 display can frame HEX on webpage
2021-03-27 nibble swap function without for loop
    [can_signal.c, can_signal.h]
2021-03-28 scematic additions
    [CANalog.sch]
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2021-03-28 preliminary csv bom output
    for inventory tracking
    [CANalog.sch, CANalog_bom_.csv]
2021-03-28 add polyfuse on usb
    [CANalog.sch, CANalog_bom_.csv]
2021-03-28 clear capacitor footprints
    [CANalog.sch]
2021-03-29 start updating part details
    [CANalog.sch]
2021-03-29 adding details
    [CANalog.sch]
2021-03-30 add more field info
    [CANalog.sch]
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2021-03-30 add CAN terminal footprint
    [CANalog.sch]
2021-03-30 add remaining footprints
    [CANalog.sch]
2021-03-30 erc cleanup
    [CANalog.sch]
2021-03-30 add custom diode 3d models
2021-03-30 add components to pcb
    [CANalog.kicad_pcb, CANalog.sch]
2021-03-31 add overvoltage protection to BL9342 enable pin
    this pin cannot exceed 5V!!!! Learned this the hard way but best to learn it now with the nucleo prototype. RIP dev board.
    [CANalog.kicad_pcb, CANalog.sch]
2021-03-31 update silkscreen and courtyard
2021-03-31 usb fuse part number change to instock
    [CANalog.sch]
2021-03-31 update ferrite with instock partnumber
    [CANalog.sch]
2021-03-31 replace agnd jumper to gnd with net tie
    [CANalog.kicad_pcb, CANalog.sch]
2021-03-31 remove ferrite bead on analog output
    [CANalog.kicad_pcb, CANalog.sch]
2021-04-01 analog ground for analog circuit section
    [CANalog.kicad_pcb, CANalog.sch]
2021-04-02 start pcb layout
    [CANalog.kicad_pcb]
2021-04-13 remove usb
    [CANalog.kicad_pcb, CANalog.sch]
2021-04-18 remove expansion headers
    [CANalog.sch]
2021-04-19 start power supply layout
    [CANalog.kicad_pcb]
2021-04-19 power supply layout
    [CANalog.kicad_pcb]
2021-04-21 update programming connectors to tc2030-idc-nl
    [CANalog.kicad_pcb, CANalog.sch]
2021-04-22 custom title block
    [CANalog.kicad_pcb, CANalog.sch]
2021-04-25 remove can_rs connection to stm32
    [CANalog.sch]
2021-04-25 stm32 pin swaping
    [CANalog.sch]
2021-04-25 move tp to pa15
    [CANalog.sch]
2021-04-25 update pcb layout, first draft
    [CANalog.kicad_pcb]
2021-04-30 clean up and silkscreen work
    [CANalog.kicad_pcb]
2021-05-04 add canalog logo
    [CANalog.kicad_pcb]
2021-05-04 cleanup pcb
    [CANalog.kicad_pcb]
2021-05-05 final cleanup
    [CANalog.kicad_pcb]
2021-05-05 output gerber
    [CANalog-B_Cu.gbr, CANalog-B_Mask.gbr, CANalog-B_Paste.gbr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]
2021-05-15 migrate STM32 code to new pn
2021-05-15 set spi data size to 8bit
2021-05-15 update iBom with DNP fields missing
    [CANalog.kicad_pcb, CANalog.sch]
2021-05-16 implement WiFi connection LED, update version to 1.0
2021-05-16 fix ibom missing R21
    [CANalog.sch]
2021-05-16 fix sn calculation array index outside of range
    [main.c]
2021-05-20 update with label
    [CANalog_V1-Enclosurebottom.amf, CANalog_V1-Enclosuretop.amf, CANalog_V1.FCStd]
2021-05-22 increase width 1mm
    [CANalog_V1.FCStd]
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2021-05-23 increase font size
    [CANalog_V1-Enclosurebottom.amf, CANalog_V1-Enclosuretop.amf]
2021-06-16 added resistor between STM32 reset land ESP8266 GPIO15
    [CANalog.kicad_pcb, CANalog.sch]
2021-06-16 clearance around terminals
    [CANalog.kicad_pcb]
2022-02-12 remove prototype firmware directory
2022-02-12 use TaskScheduler lib for web socket.
2022-02-12 spi is receiving data not sending
2022-02-13 manual analog output control for calibration
2022-02-13 update to kicad 6
    [CANalog.kicad_pcb, CANalog.kicad_sch]
2022-02-13 move to separate dir
    [CANalog-B_Cu.gbr, CANalog-B_Mask.gbr, CANalog-B_Paste.gbr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]
2022-02-13 create tag-connect adapter
    [tag-connect_base-base.amf, tag-connect_base.FCStd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]
2022-02-19 upgrade to stm32cubeide 1.8

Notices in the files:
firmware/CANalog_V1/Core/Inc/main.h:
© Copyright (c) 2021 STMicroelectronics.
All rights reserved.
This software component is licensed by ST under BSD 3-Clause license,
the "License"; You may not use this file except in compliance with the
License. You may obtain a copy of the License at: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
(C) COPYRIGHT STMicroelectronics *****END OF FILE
